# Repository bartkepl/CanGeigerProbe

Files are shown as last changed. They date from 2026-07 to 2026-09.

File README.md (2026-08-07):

# CanGeigerProbe
## Sonda promieniowania G-M z interfejsem CAN

Polowa sonda promieniowania jonizującego z miniaturową lampą Geigera-Müllera, komunikująca się cyfrowo przez **CAN 2.0B**. Zaprojektowana jako element rozproszonego systemu pomiarowego: wąska sonda cylindryczna w obudowie aluminiowej, jedno złącze M12, micropower, odporność EMC klasy przemysłowej.







> **Status:** schemat (6 arkuszy hierarchicznych) i layout PCB zakończone, pliki produkcyjne wygenerowane — przed zamówieniem prototypu. Firmware na etapie szkieletu bring-up.

Inspiracja: sondy Polon-Alfa (DPO-G, ZR-1) — jedna sonda, cyfrowe wyjście do jednostki nadrzędnej, wymienność lamp.

---

## Płytka

Render 3D aktualnego layoutu (KiCad 10, 4 warstwy, 86 × 29.9 mm, wycięcie pod złącze M12 na lewej krawędzi):

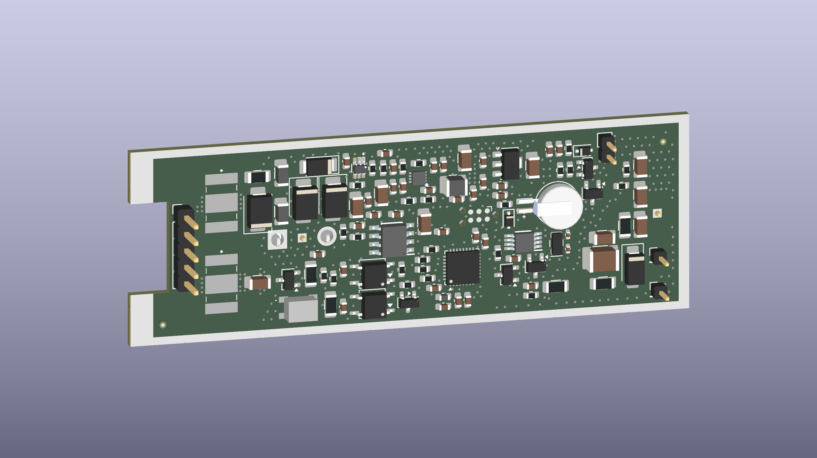
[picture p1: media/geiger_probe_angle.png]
Sonda G-M — widok pod kątem


| Góra (TOP) | Dół (BOTTOM) |
|---|---|
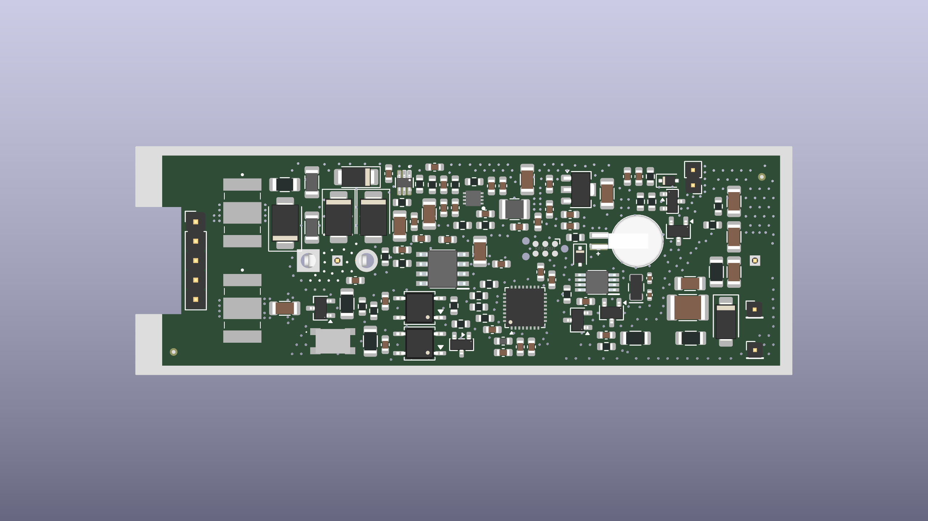
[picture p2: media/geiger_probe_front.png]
TOP
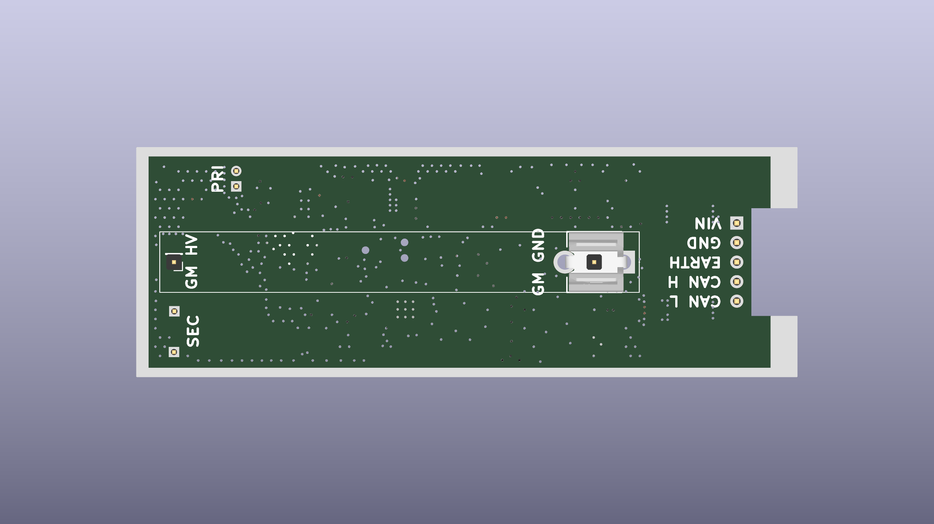
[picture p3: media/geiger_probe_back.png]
BOTTOM
|  |  |

Cała elektronika mieści się na jednej stronie; spód pozostaje niemal pusty — rezerwa na strefę HV (widoczny prostokąt creepage z pinami anody i lampy), pole lutownicze wyprowadzeń transformatora oraz uziemienie obudowy. Transformator flybacka jest **off-board** (skręcona para przewodów 4–6 cm).

---

## Najważniejsze cechy

- **Programowalne HV 350–550 V** — jedna sonda obsługuje wiele typów lamp, setpoint ustawiany przez CAN bez zmian sprzętowych.
- **Micropower** — pobór idle rzędu setek µA dzięki buckowi LT8606 (Iq 2.5 µA), MCU w Stop 2 i podwójnemu wybudzaniu (RTC + aktywność magistrali).
- **Flyback sterowany deterministycznie z MCU** — brak dedykowanego kontrolera PWM; TIM2 generuje burst, ADC mierzy HV, firmware zamyka pętlę bang-bang.
- **CAN 2.0B (29-bit ID)** z wybudzaniem na aktywność magistrali, 125 kbit/s – 1 Mbit/s.
- **Przełączalna terminacja CAN** — split 2×59 Ω + 4.7 nF załączany dwoma PhotoMOS-ami z GPIO (sonda na końcu linii vs. w środku, bez zwór).
- **Pomiar własnego poboru prądu** — INA186 A4 (G=200) + shunt 0.5 Ω, rozdzielczość ~2 µA/count; diagnostyka linii i weryfikacja budżetu mocy.
- **Zegar czasu rzeczywistego z podtrzymaniem** — MCP79410 + ogniwo MS621FE; kwarc 32.768 kHz służy też do kalibracji wewnętrznego MSI w STM32.
- **Wymienność lamp** — rezystor gaszący `R12` na PCB dobierany pod konkretną lampę.
- **Odporność EMC** — kaskadowa ochrona coarse→fine (GDT 3-elektrodowe / TVS / CMC / podwójne ferryty), testy IEC 61000-4-2/-4/-5.
- **Obudowa aluminiowa IP67**, złącze M12 5-pin A-coded (standard CANopen CiA 303-1).

---

## Specyfikacja

| Parametr | Wartość |
|---|---|
| Detektor bazowy | DOI-80 (~400 V) |
| Zakres HV | 350–550 V, programowalny |
| Wielkości mierzone | CPS/CPM, moc dawki, dawka skumulowana, prąd zasilania, alarmy progowe |
| Interfejs | CAN 2.0B (extended ID), 125k / 250k / 500k / 1 Mbit |
| Zasilanie | 7–32 V DC, wspólna masa (bez izolacji galwanicznej) |
| Pobór idle | ~200 µA @ 12 V |
| Pobór aktywny | ~3.7 mA @ 12 V (chwilowo), do ~20 mA przy TX CAN @ 7 V |
| Ochrona EMC | ESD ±8 kV, Burst ±2 kV, Surge ±2 kV |
| Złącze | M12 5-pin A-coded (1=Vin, 2=GND, 3=CAN_H, 4=CAN_L, 5=Earth) |
| PCB | 4 warstwy, 86 × 29.9 mm, grubość 1.59 mm |
| Obudowa | Aluminiowa cylindryczna Ø wewn. 25 mm, IP67 |

---

## Kompatybilne lampy G-M

Zmiana lampy = zmiana programowa HV + dobór rezystora gaszącego `R12`.

| Lampa | HV nom. | R12 (quench) | Uwaga |
|---|---|---|---|
| **DOI-80** | ~400 V | **5.1 MΩ** | domyślna |
| SBM-20 / STS-5 | 400 V | 4.7 MΩ | drop-in z DOI-80 |
| SBM-19 | ~400 V | 5.1 MΩ | |
| J305 / M4011 | ~400 V | 4.7 MΩ | lampy chińskie |
| LND712 | 500 V | 10 MΩ | wymaga wyższego HV |

Rezystor HV w obudowie 1206 (HVC1206) — lutowany wg używanej lampy.

---

## Architektura

```
M12 Vin (7-32V) ─▶ Ochrona (GDT+TVS+ferryt) ─▶ shunt 0.5Ω ─▶ LT8606 buck ─▶ +5V ─┬─▶ ATA6561 (CAN)
                                                    │                              │
                                                 INA186 ─▶ ADC                     ├─▶ MCP1700 LDO ─▶ +3.3V ─▶ STM32L432
                                                                                   │                              │
                                                                                   │                     MCP79410 RTC + BT1
                                                                                   │
                                                                                   └─▶ Flyback (Q1 + T1 P18/11) ─▶ +HV
                                                                                                                    │
   Lampa G-M ◀─ R12 (quench) ◀─ dzielnik HV 1GΩ:1MΩ ◀─────────────────────────────────────────────────────────────┘
        │
        └─▶ dzielnik pojemnościowy ─▶ COMP1 (próg z DAC1) ─▶ LPTIM (zliczanie w Stop 2)
```

Kluczowa cecha: **wspólna masa** (star ground), izolacja zapewniona wyłącznie przez TVS/GDT; `Earth` (obudowa) oddzielona od `GND` sygnałowej i łączona tylko przez Y-cap 1 nF/2 kV. Flyback „śpi" i budzi się kilka razy na sekundę — stąd pobór na poziomie µA.

### Arkusze schematu

| Arkusz | Plik | Zawartość |
|---|---|---|
| root | [geiger_probe.kicad_sch](pcb/geiger_probe.kicad_sch) | połączenia hierarchiczne |
| PWR | [pwr.kicad_sch](pcb/pwr.kicad_sch) | buck LT8606, LDO MCP1700, INA186, dzielnik VIN_SENSE |
| MCU | [mcu.kicad_sch](pcb/mcu.kicad_sch) | STM32L432, RTC MCP79410, kwarc 32k, SWD (Tag-Connect) |
| HV | [hv.kicad_sch](pcb/hv.kicad_sch) | flyback (trafo, Q1, snubber RCD), dzielnik HV, detektor GM + shaper |
| CAN_BUS | [can_bus.kicad_sch](pcb/can_bus.kicad_sch) | ATA6561, terminacja PhotoMOS |
| PROTECTION | [prot.kicad_sch](pcb/prot.kicad_sch) | ochrona Vin i CAN, złącze M12 |

Wyrenderowane PDF-y: [schemat](prod/sch/geiger_probe.pdf) · [PCB](prod/pcb/geiger_probe.pdf) · [interaktywny BOM](prod/ibom/geiger_probe_ibom.html).

---

## Kluczowe komponenty

| Blok | Element | Uwaga |
|---|---|---|
| Buck | LT8606IDC#TRPBF | DFN-8, Iq 2.5 µA (zawsze Burst Mode), Vref FB 0.778 V — jedyny element spoza TME |
| LDO 3.3 V | MCP1700-3302E/MB | SOT-89, Iq 1.6 µA |
| Current sense | INA186A4IDCKR + 0.5 Ω | 40 V CM, G=200, pin EN — pomiar poboru sondy |
| MCU | STM32L432KCU6 | bxCAN, LPTIM, COMP1, TIM2, ADC, DAC1 |
| RTC | MCP79410-I/MS + MS621FE-FL11E | RTC/EEPROM I2C z podtrzymaniem, kwarc 32.768 kHz |
| CAN | ATA6561-GAQW-N | zamiennik TJA1042 dostępny w TME |
| Terminacja CAN | 2× GAQY212GS + 2× 59 Ω + 4.7 nF | split przełączalny, sterowany BSS138 |
| Transformator | własny P18/11-3F3, 17:510 | nawijany ręcznie, off-board |
| Klucz flyback | DMN3404L | 30 V, snubber RCD (BAV21WS) clamp do +5 V |
| Dioda HV | STTH112A | 1200 V |
| Dzielnik HV | 2× HVC1206 500 MΩ | /1001, ochrona ADC diodami BAV199 |
| Ochrona Vin | 3R090-5S (GDT) + SMBJ33CA + PMEG6030EP + 2× SMBJ36A | kaskada coarse→fine, podwójny ferryt BLM31 |
| Ochrona CAN | 3R090-5S + CDSOT23-T24CAN + ACT45B-510 | GDT, dedykowany TVS, CMC |

Pełna lista: [prod/bom/](prod/bom/) (generowana z KiCad, nietrackowana w git). Szacunkowy koszt kompletu: **~160–200 zł**.

---

## Transformator (DIY)

Najbardziej „ręczna" część projektu — rdzeń kubełkowy **P18/11-3F3**, mocowany śrubą **M2 A2 (nierdzewna, niemagnetyczna!)** z podkładkami nylonowymi chroniącymi kruchy ferryt.

- Pierwotne: **17 zw** drut 0.30 mm CuL
- Wtórne: **510 zw** drut 0.10 mm CuL (przekładnia 1:30)
- Szczelina: Kapton 100 µm między połówkami
- Parametry docelowe: Lp ≈ 75 µH, Ls ≈ 67 mH, leakage < 1.5 µH, izolacja P/S > 1 GΩ

Zasilany z **+5 V** (nie z Vin), snubber RCD clamp do +5 V — recykling energii rozproszenia, Vds ~20 V, cichy EMC. Procedura nawijania, obliczenia i testy (hi-pot 1 kV/60 s) — patrz dokumentacja projektowa.

---

## Firmware

Projekt STM32CubeIDE w [firmware/CanGeigerProbe/](firmware/CanGeigerProbe/) — na razie szkielet wygenerowany z CubeMX ([CanGeigerProbe.ioc](firmware/CanGeigerProbe/CanGeigerProbe.ioc)) z inicjalizacją ADC1, CAN1, COMP1, DAC1, I2C1 i TIM2. Logika aplikacji (pętla HV, zliczanie w Stop 2, protokół CAN) do napisania.

---

## Roadmap

- [x] **Faza 1** — projekt: topologia, dobór komponentów, obliczenia, EMC, budżet mocy
- [ ] **Faza 2** — prototyp transformatora (nawinięcie, strojenie, testy)
- [x] **Faza 3** — schemat i layout PCB w KiCad (strefy HV / analog / cyfrowe), pliki produkcyjne wygenerowane
- [ ] **Faza 3b** — zamówienie PCB, montaż sekcyjny, bring-up sprzętowy
- [ ] **Faza 4** — firmware (LPTIM+COMP w Stop 2, pętla HV, bxCAN + wake-up, RTC/kalibracja MSI, current-sense, protokół)
- [ ] **Faza 5** — kalibracja HV per lampa, kalibracja CPS→µSv/h (Cs-137), testy EMC
- [ ] **Faza 6** — mechanika: obudowa Al, montaż M12, testy IP67

---

## Struktura repozytorium

```
.
├── media/          # rendery 3D płytki
├── pcb/            # projekt KiCad 10 (schemat hierarchiczny, PCB, biblioteki lokalne, modele 3D)
├── prod/           # pliki produkcyjne: gerbery (.zip), PDF schematu i PCB, interaktywny BOM
├── sim/            # symulacje LTspice (flyback HV, LT8606)
└── firmware/       # projekt STM32CubeIDE (STM32L432, szkielet bring-up)
```

Pliki produkcyjne generowane są jobsetami KiCad: [gen_prod.kicad_jobset](pcb/gen_prod.kicad_jobset) (PDF + BOM), [gen_gerber.kicad_jobset](pcb/gen_gerber.kicad_jobset) (gerbery + wiertła), [gen_media.kicad_jobset](pcb/gen_media.kicad_jobset) (rendery 3D).

---

## Referencje

- Analog Devices **CN-0536** — Geiger Counter Circuit (odczyt z anody, dzielnik pojemnościowy, komparator)
- STM32L432: RM0394, DS11453; bxCAN: AN2606, AN5028
- LT8606 (Analog Devices), MCP1700 / MCP79410 / ATA6561 (Microchip), INA186 (TI)
- Ferroxcube P18/11, materiał 3F3; EPCOS/TDK B65651/B65652
- IEC 61000-4-2/-4/-5; EN 61326-1; EN 61000-6-2
- CAN 2.0B: ISO 11898-1/-2; CANopen CiA 301, CiA 303-1; M12: IEC 61076-2-101
- Polski podręcznik metrologii promieniowania — układy pracy liczników DOI/BOI/GOI

---

## Licencja

MIT

---

> ⚠️ **Uwaga bezpieczeństwa:** urządzenie generuje napięcie ~350–550 V. Zachowaj ostrożność przy uruchamianiu i pomiarach obwodów HV.

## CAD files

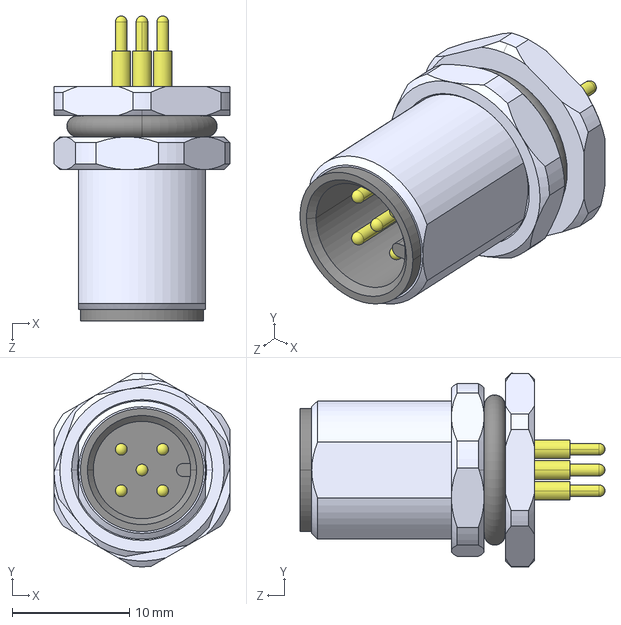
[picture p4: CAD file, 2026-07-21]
pcb/lib_local/CDM1209-05A-MP-F12-67.step
15.0 x 16.5 x 26.0 mm
CDM1209 HOUSING
PINS_MALE_REAR_5P

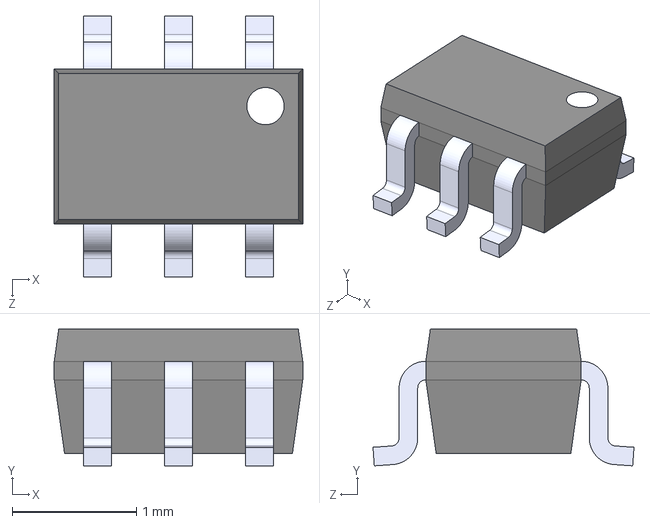
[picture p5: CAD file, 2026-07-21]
pcb/lib_local/INA186A4IDCKR.step
2.00 x 1.10 x 2.10 mm

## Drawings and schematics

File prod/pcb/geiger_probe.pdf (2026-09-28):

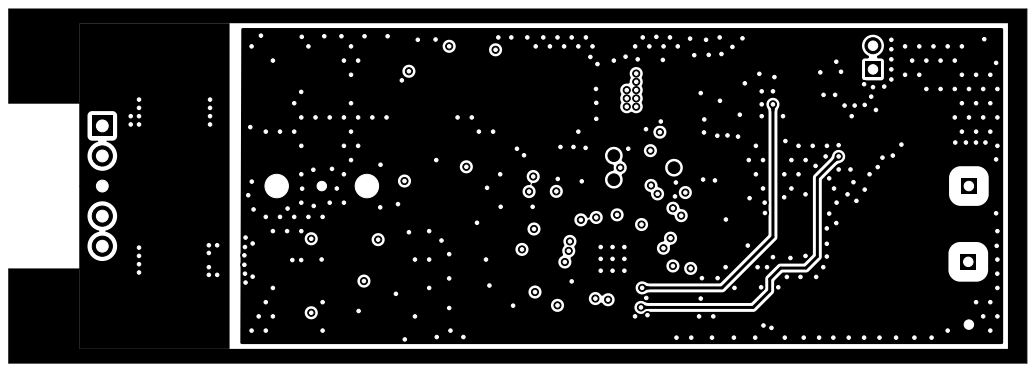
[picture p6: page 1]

Size: A4 | Rev:
KiCad E.D.A. 10.0.4 | Id: 1/6

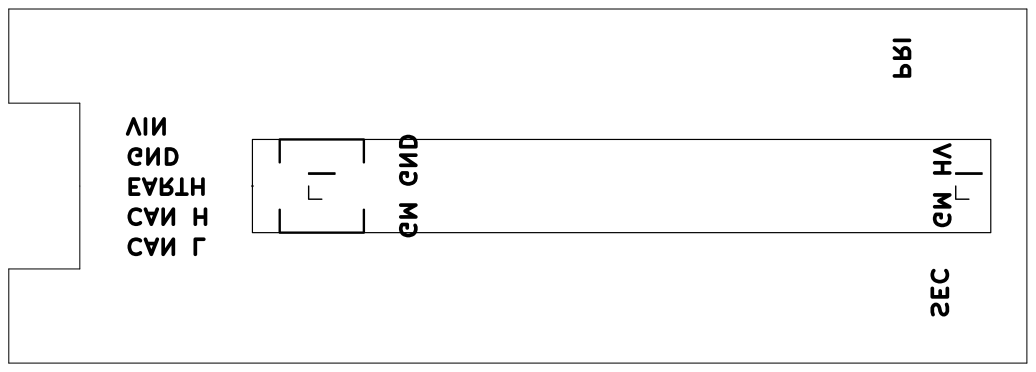
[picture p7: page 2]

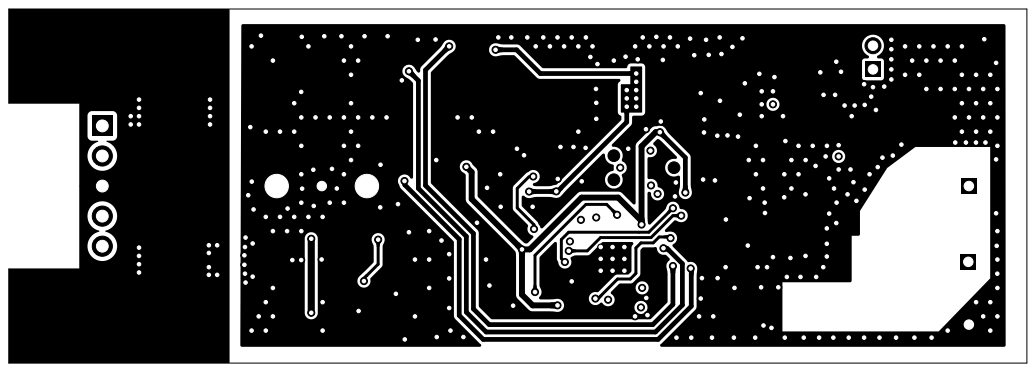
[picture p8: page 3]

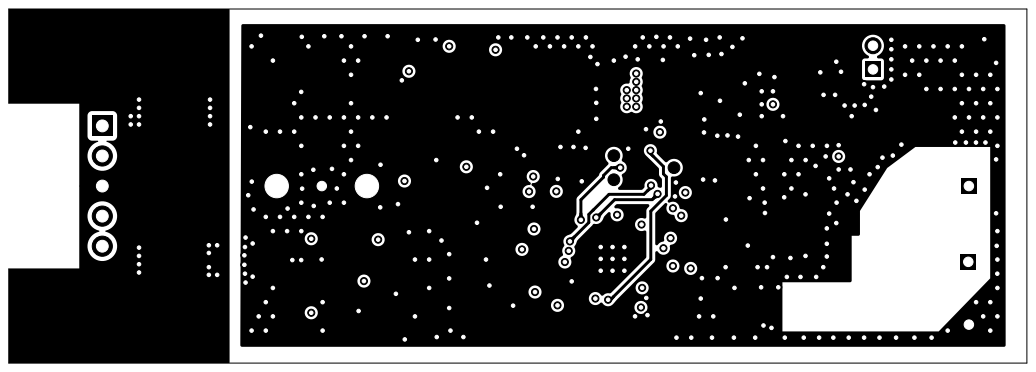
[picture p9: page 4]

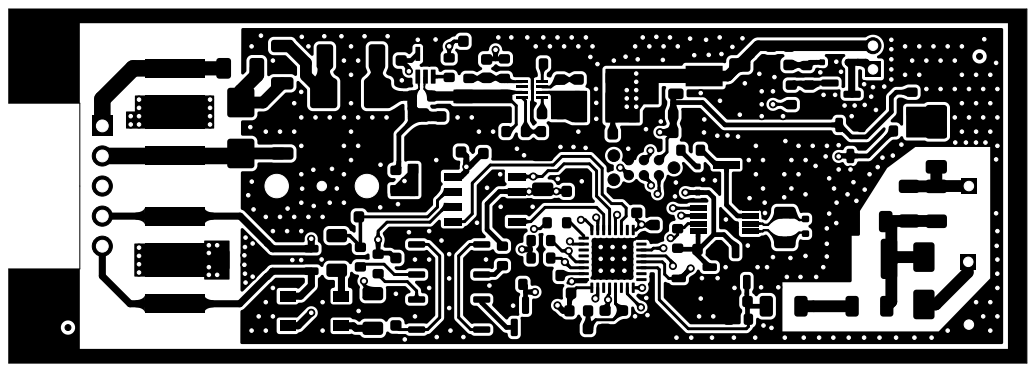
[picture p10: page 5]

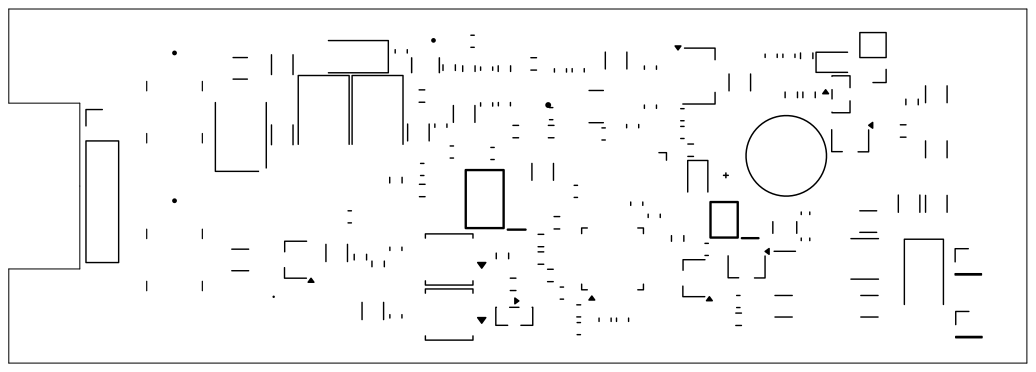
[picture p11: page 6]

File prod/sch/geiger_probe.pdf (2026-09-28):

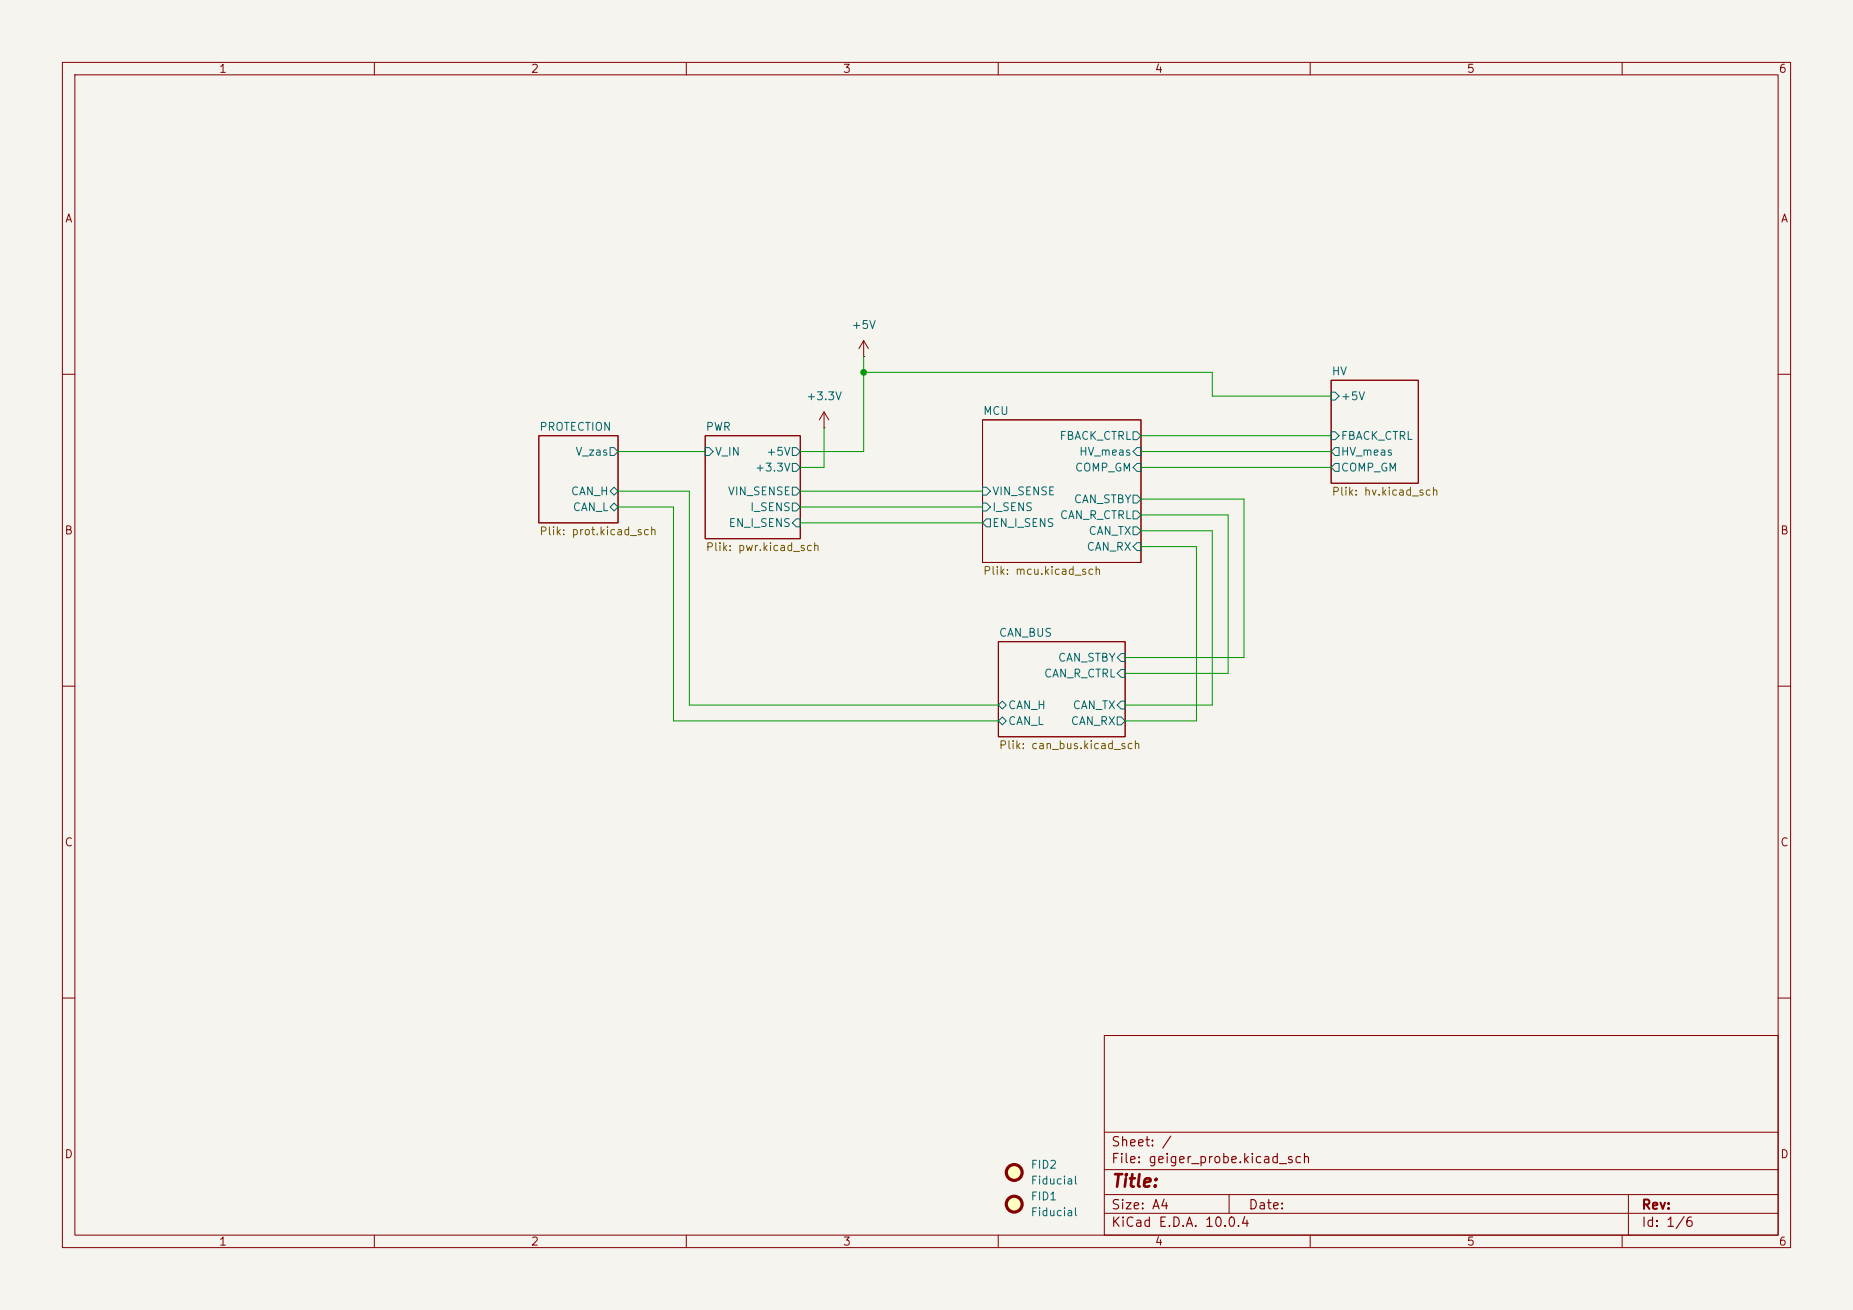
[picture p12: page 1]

Size: A4 | Rev:
KiCad E.D.A. 10.0.4 | Id: 1/6

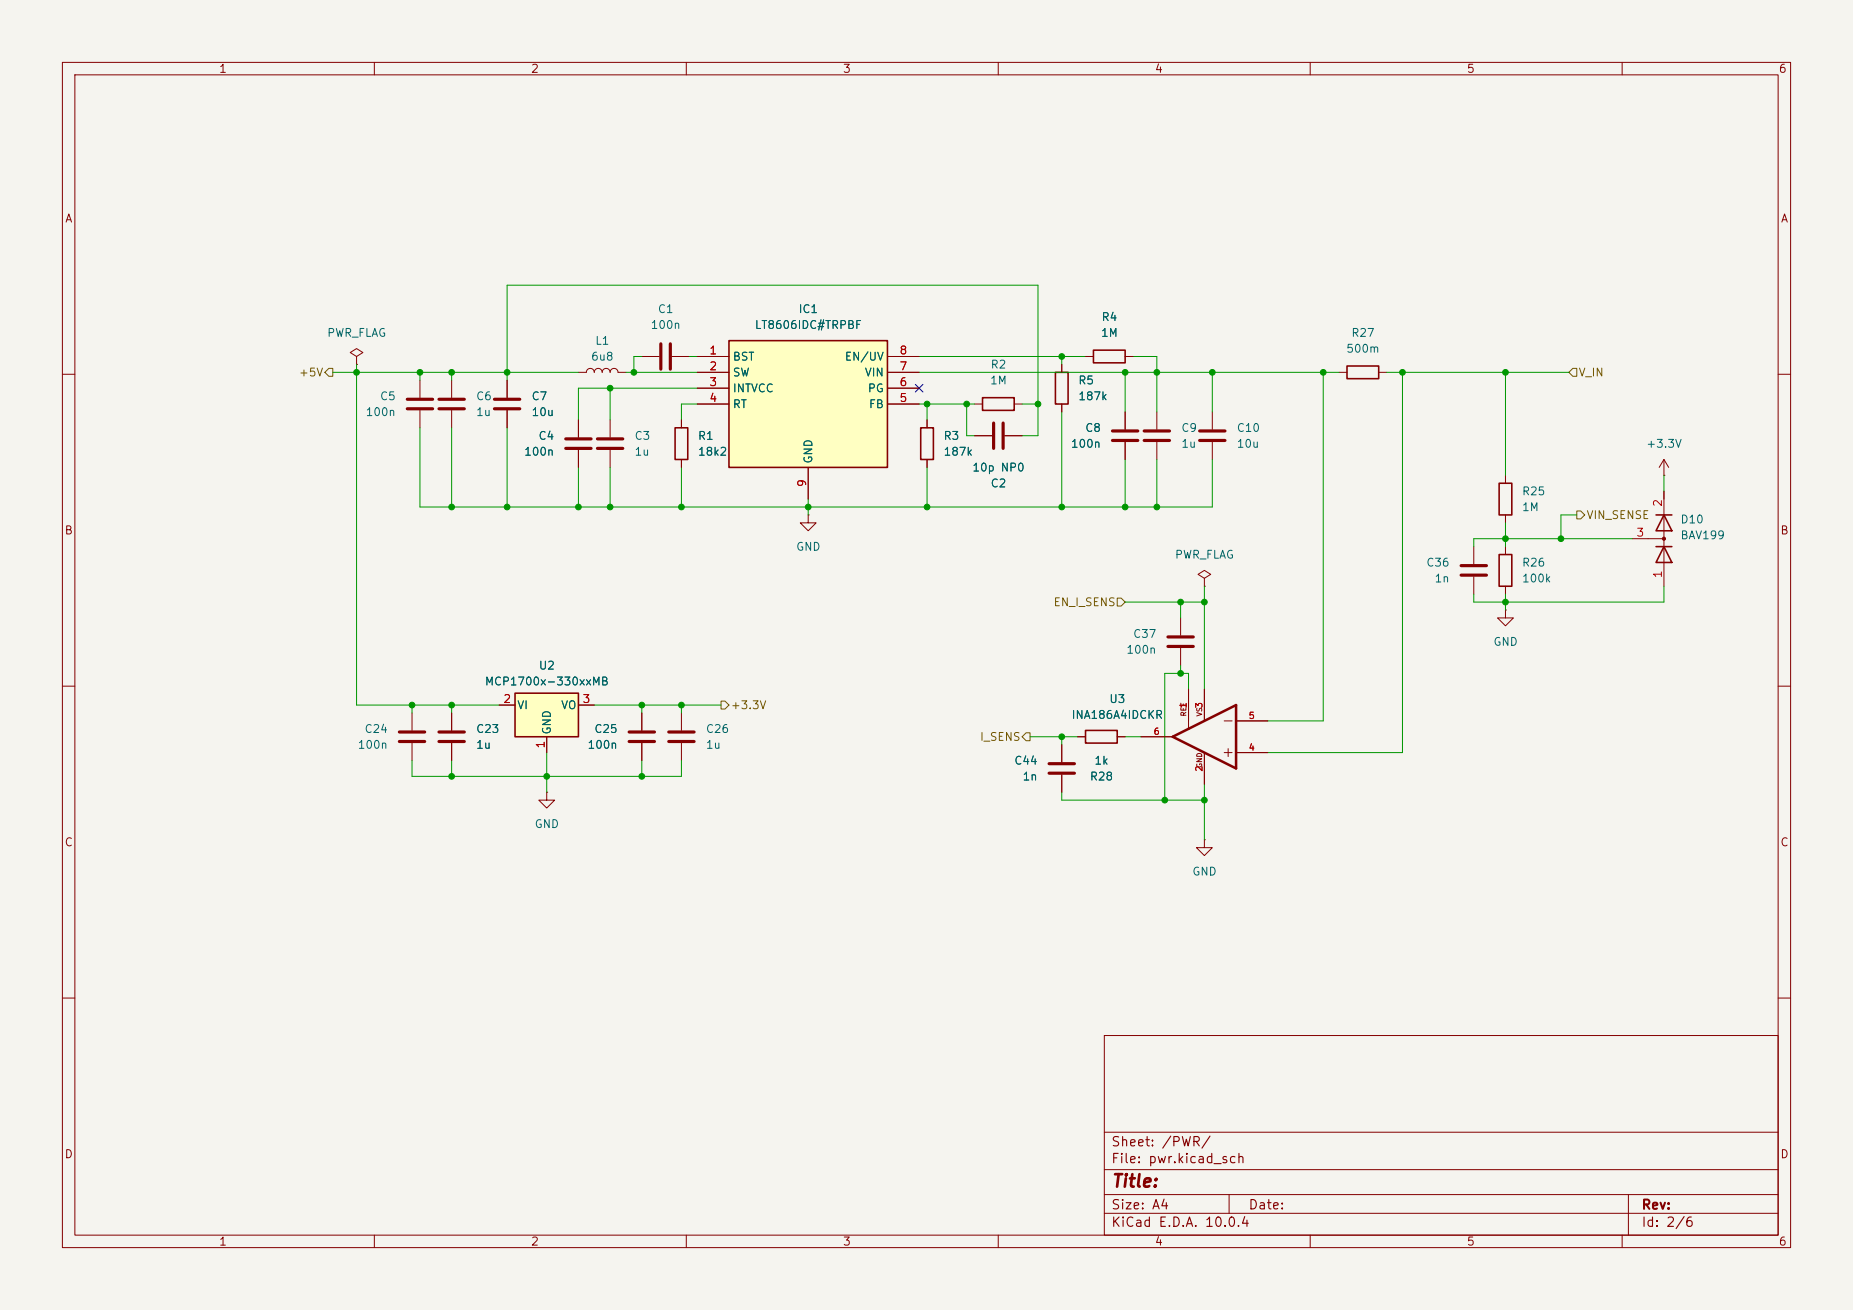
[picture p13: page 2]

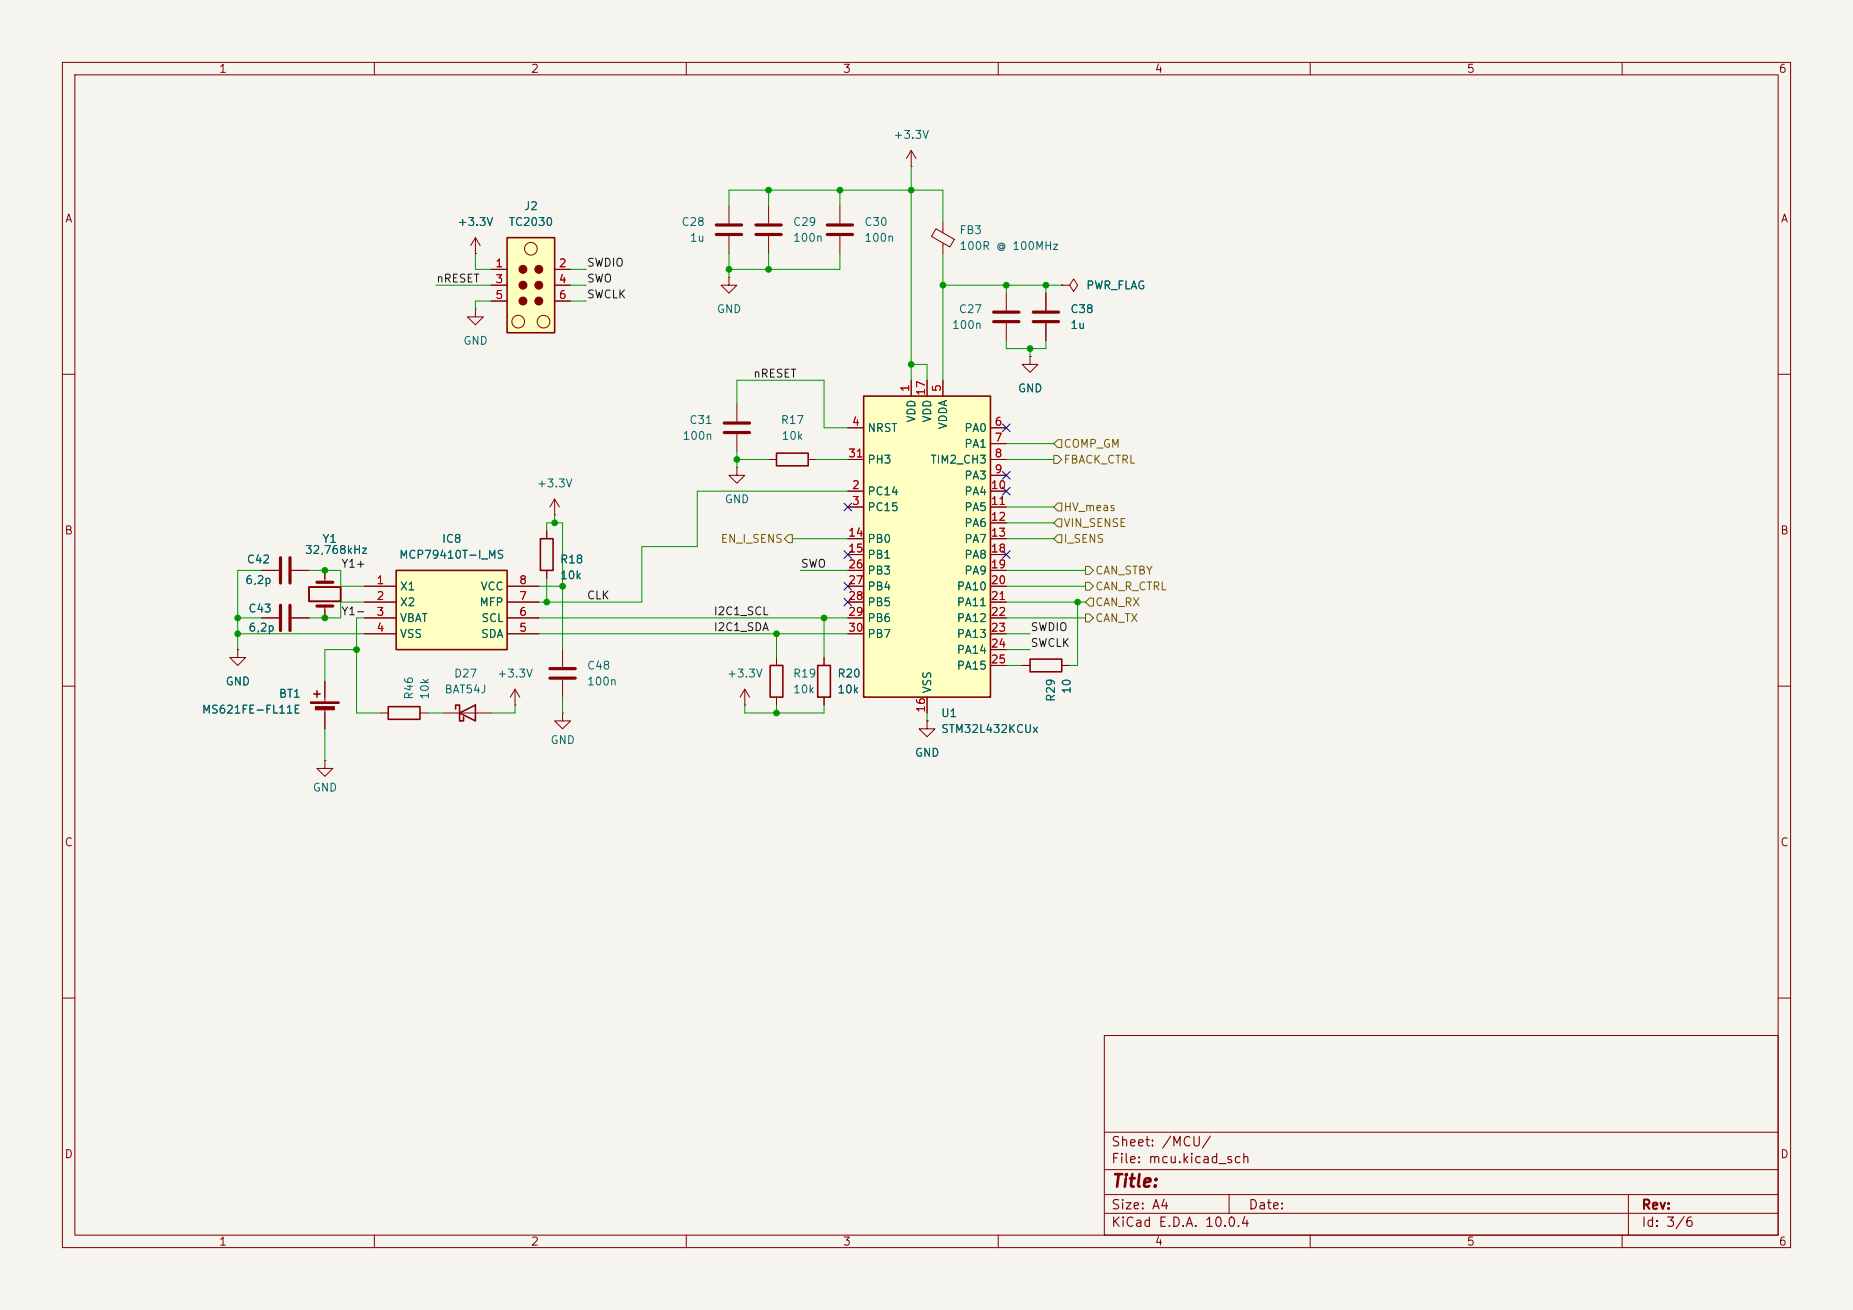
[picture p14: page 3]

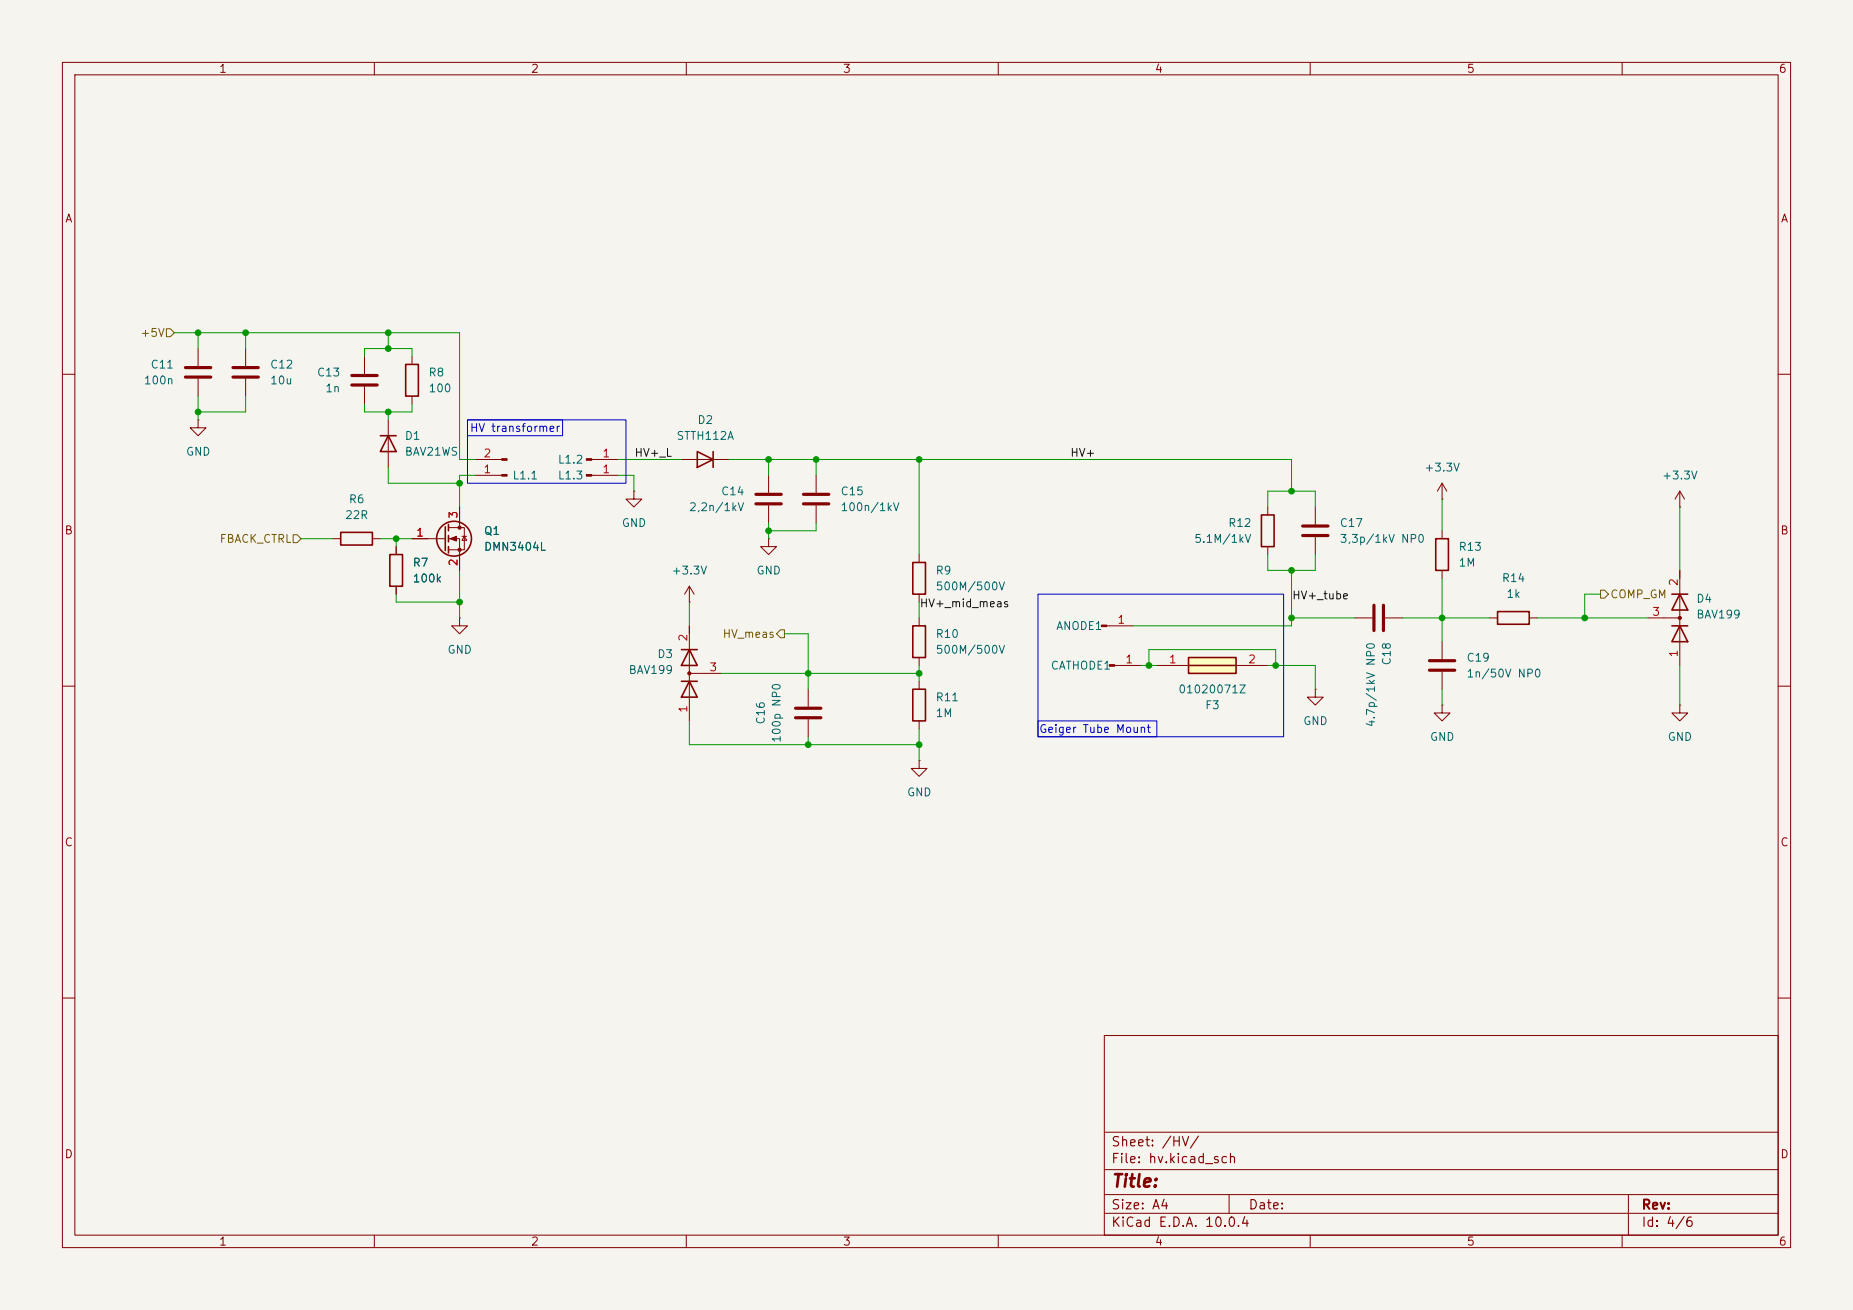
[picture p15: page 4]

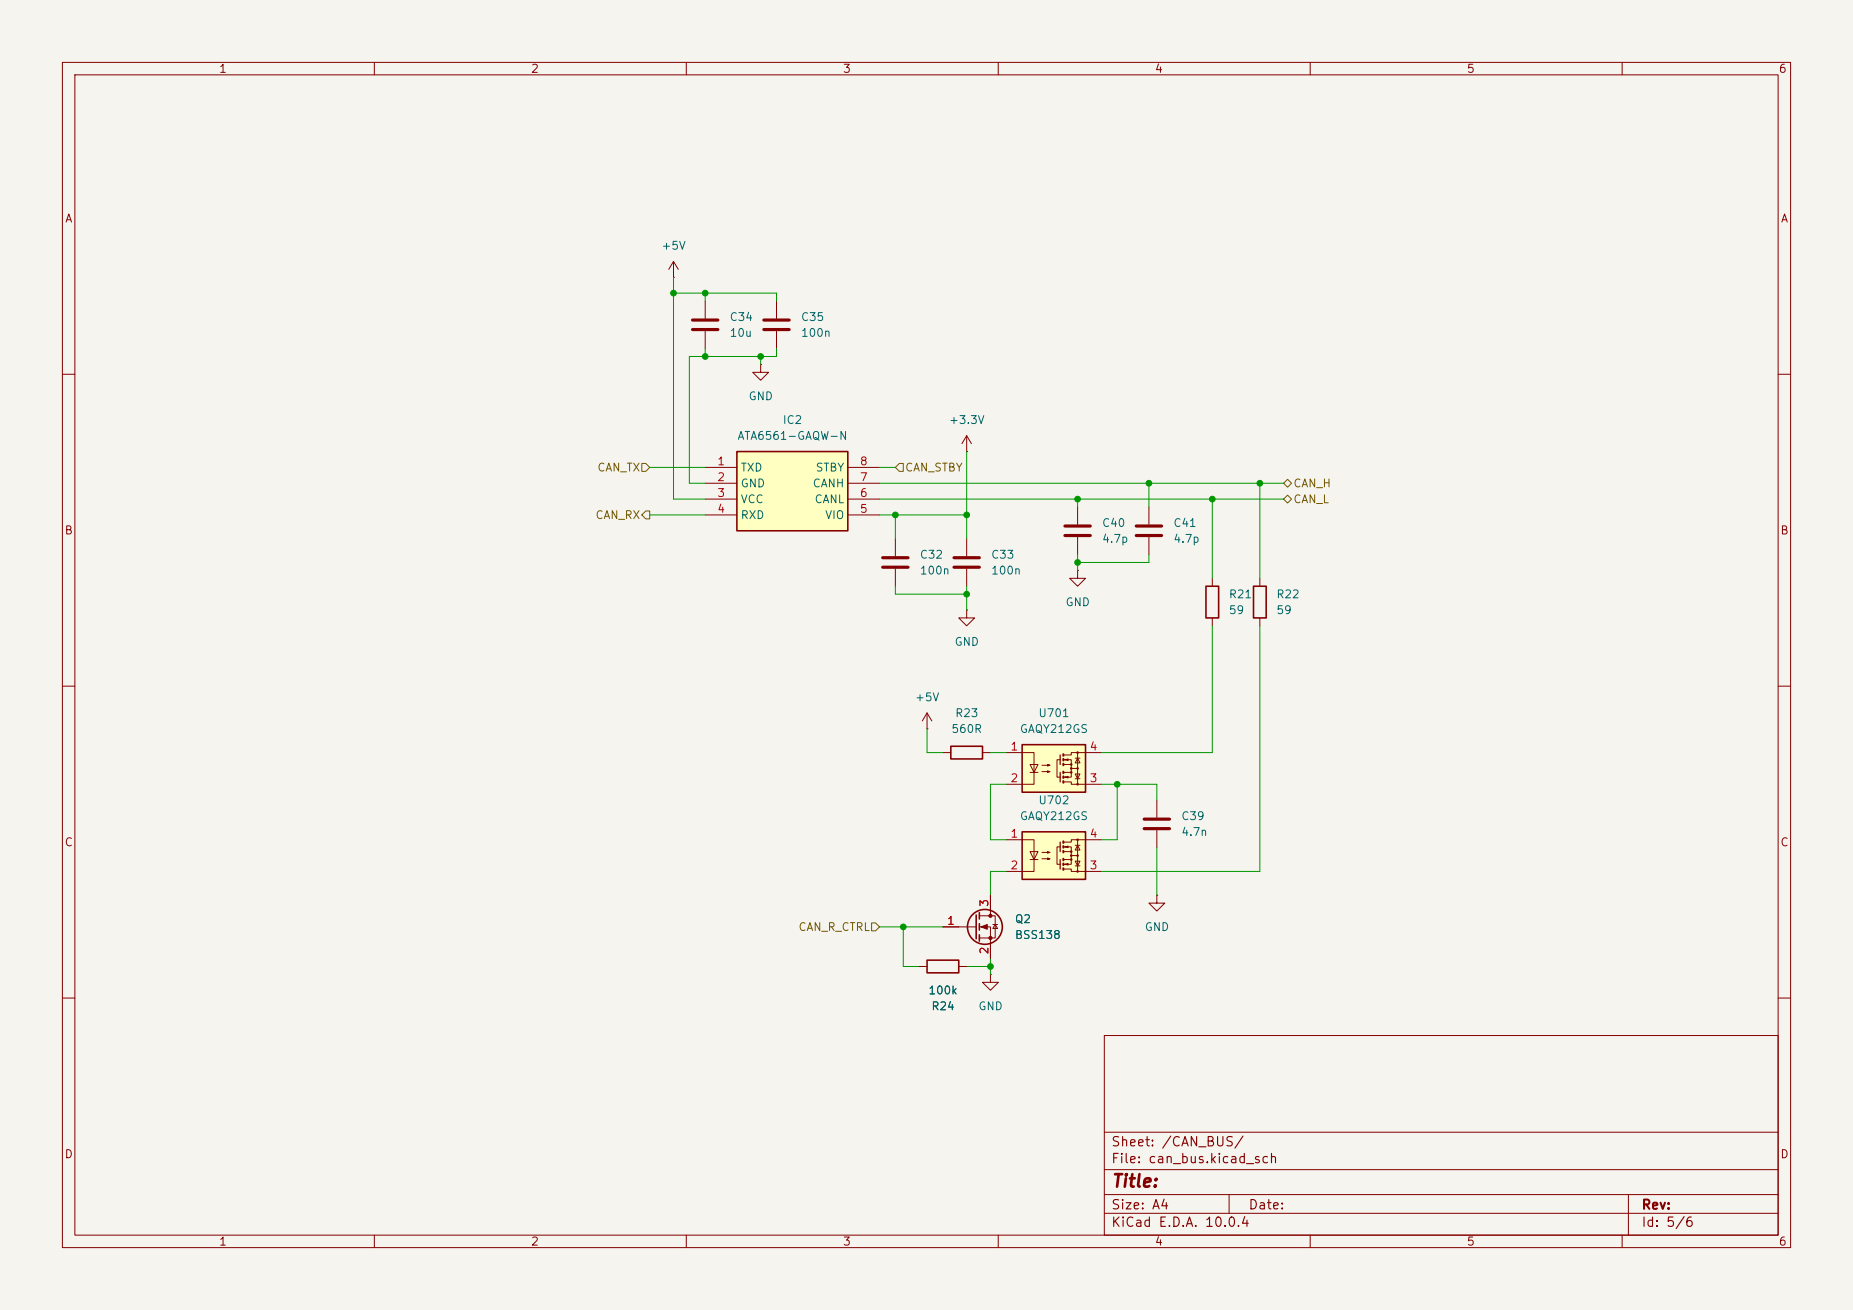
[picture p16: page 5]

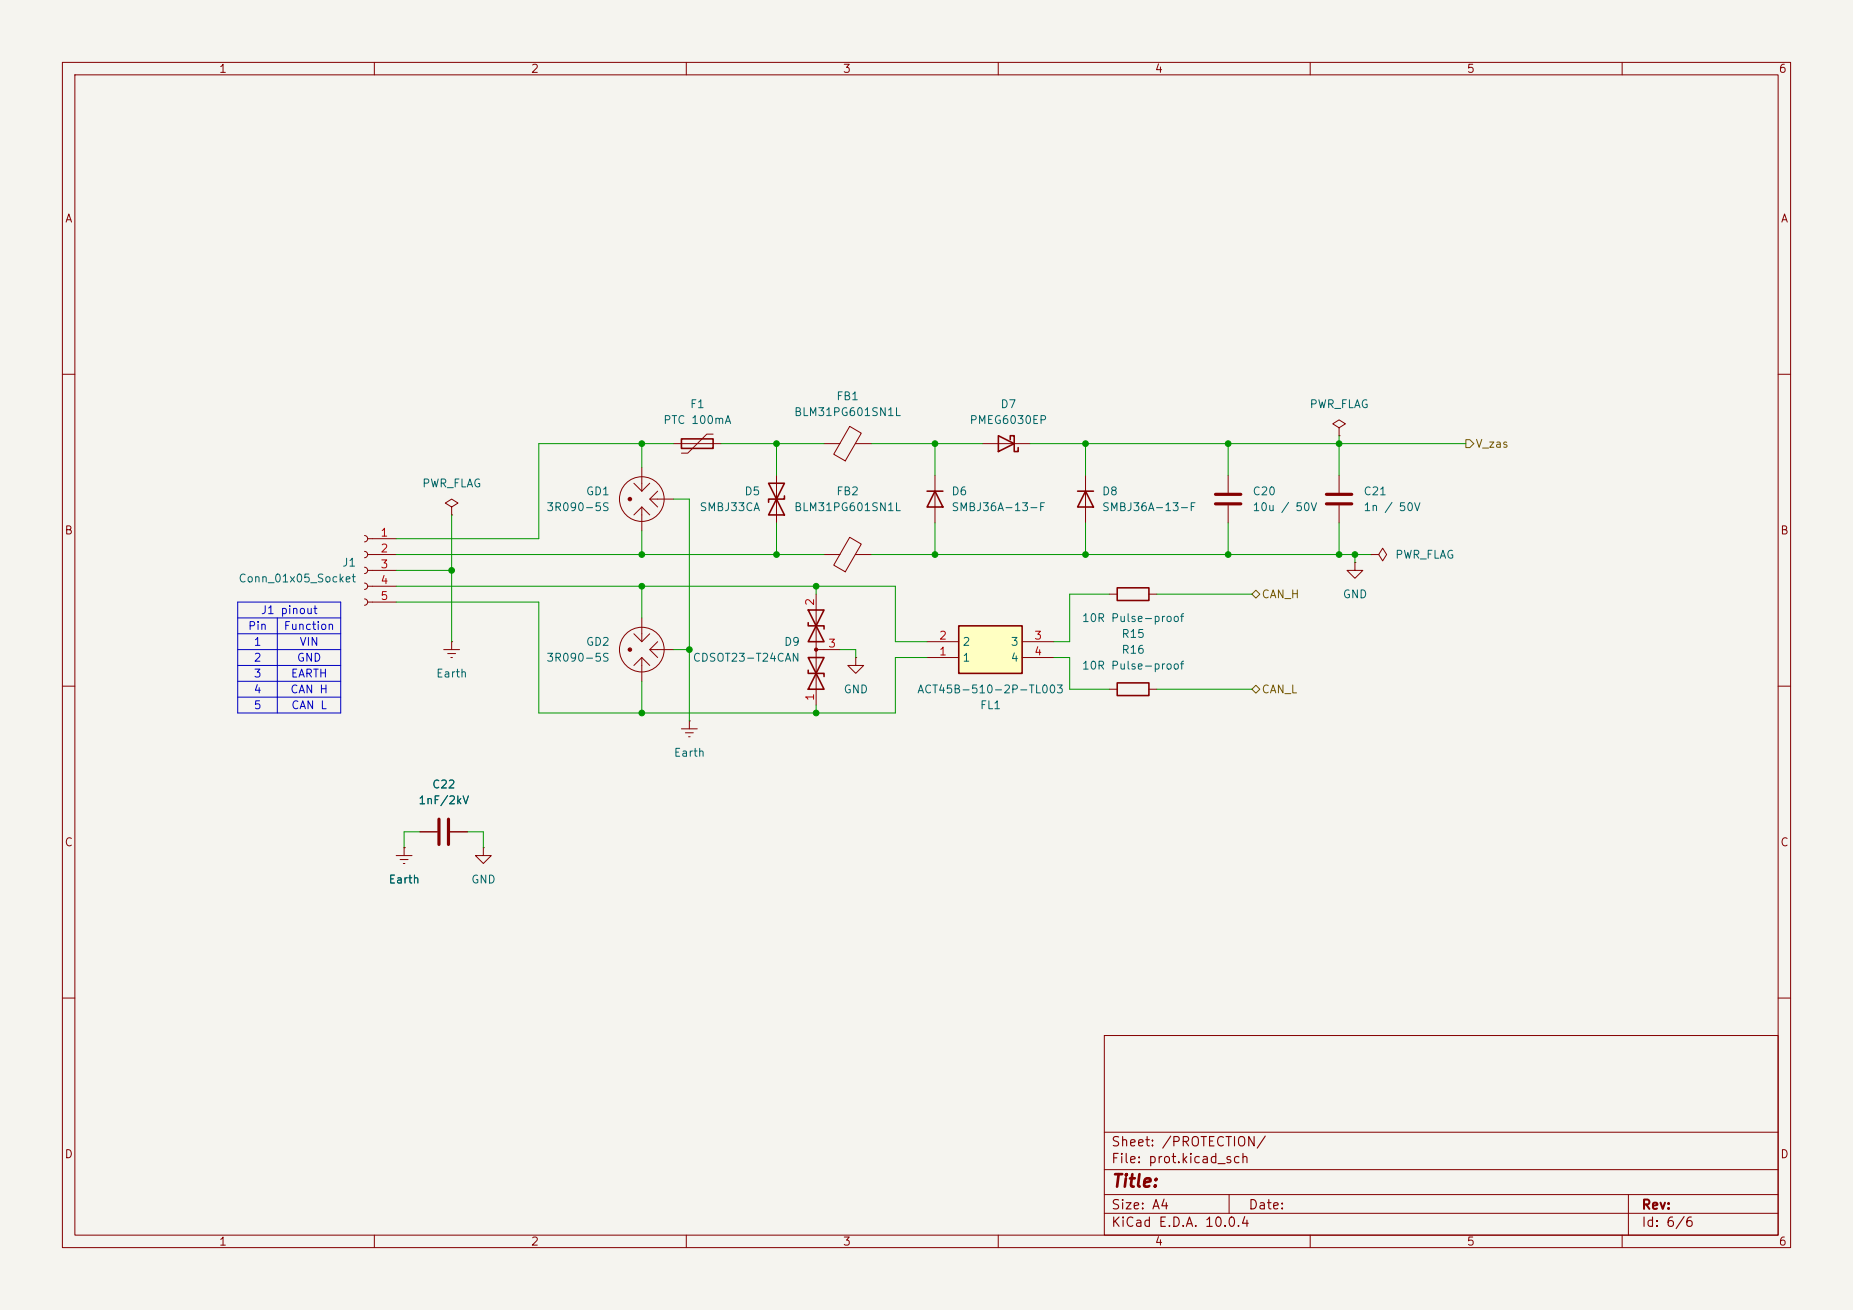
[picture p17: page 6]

J1 pinout Pin | Function 1 VIN

2 | GND
3 | EARTH
4 | CAN H

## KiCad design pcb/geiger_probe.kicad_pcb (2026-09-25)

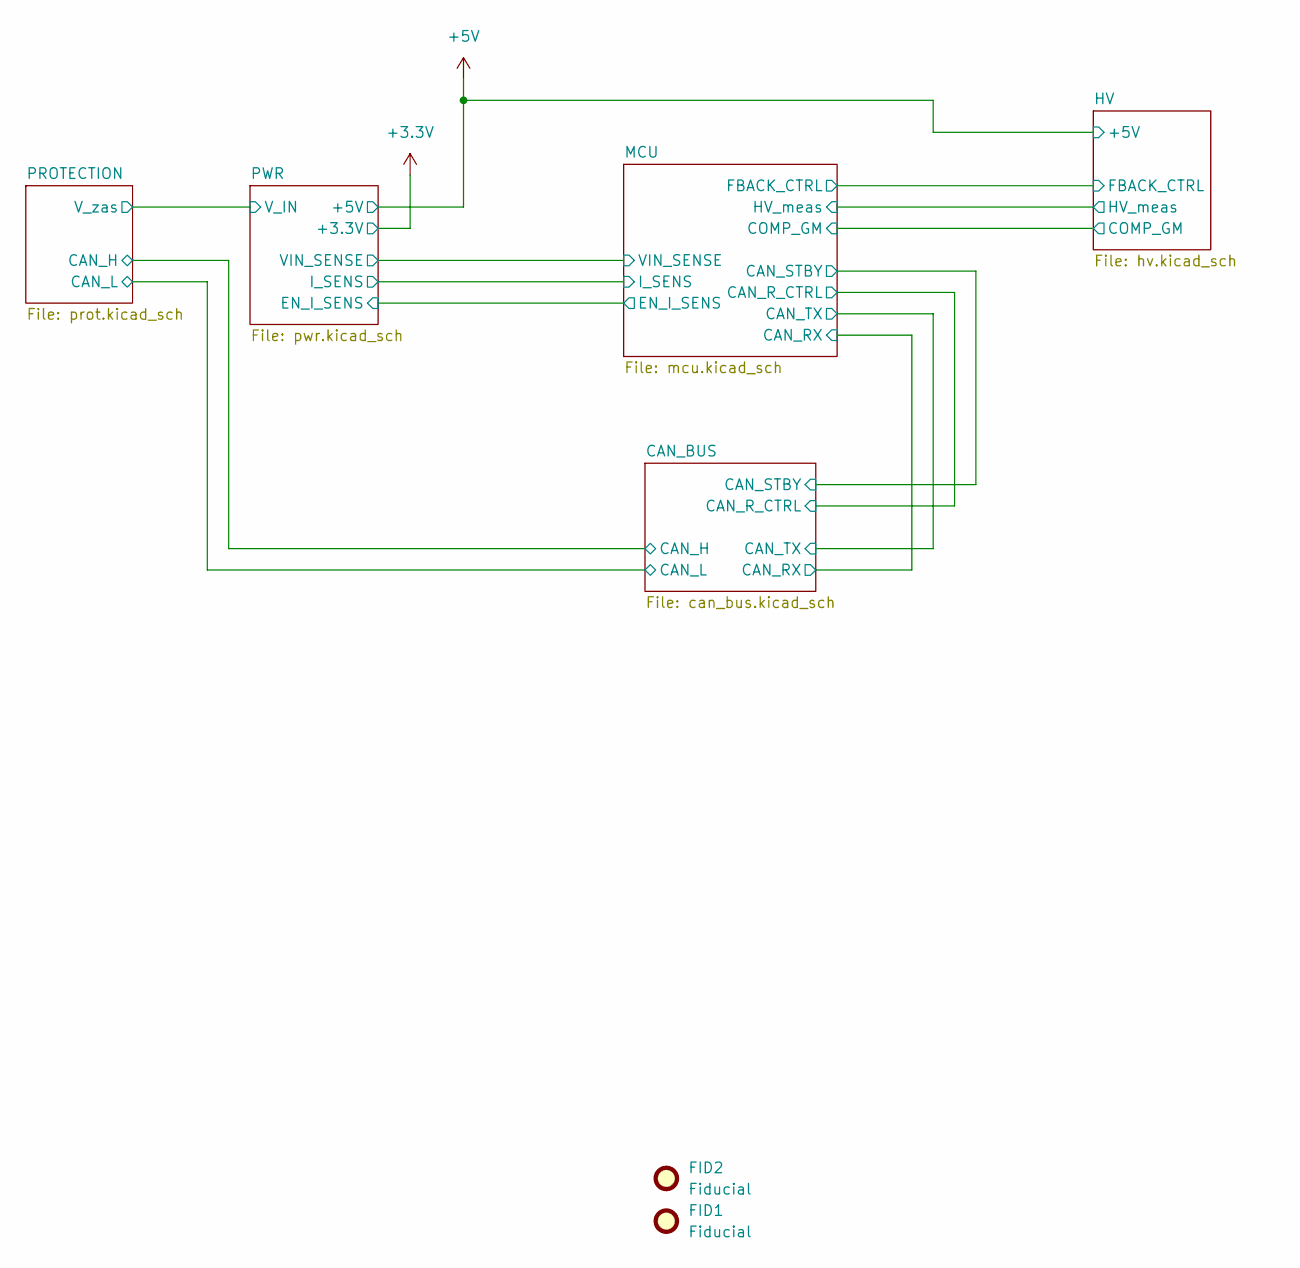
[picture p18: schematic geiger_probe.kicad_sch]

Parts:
FID1, FID2: Fiducial; Fiducial_0.5mm_Mask1mm

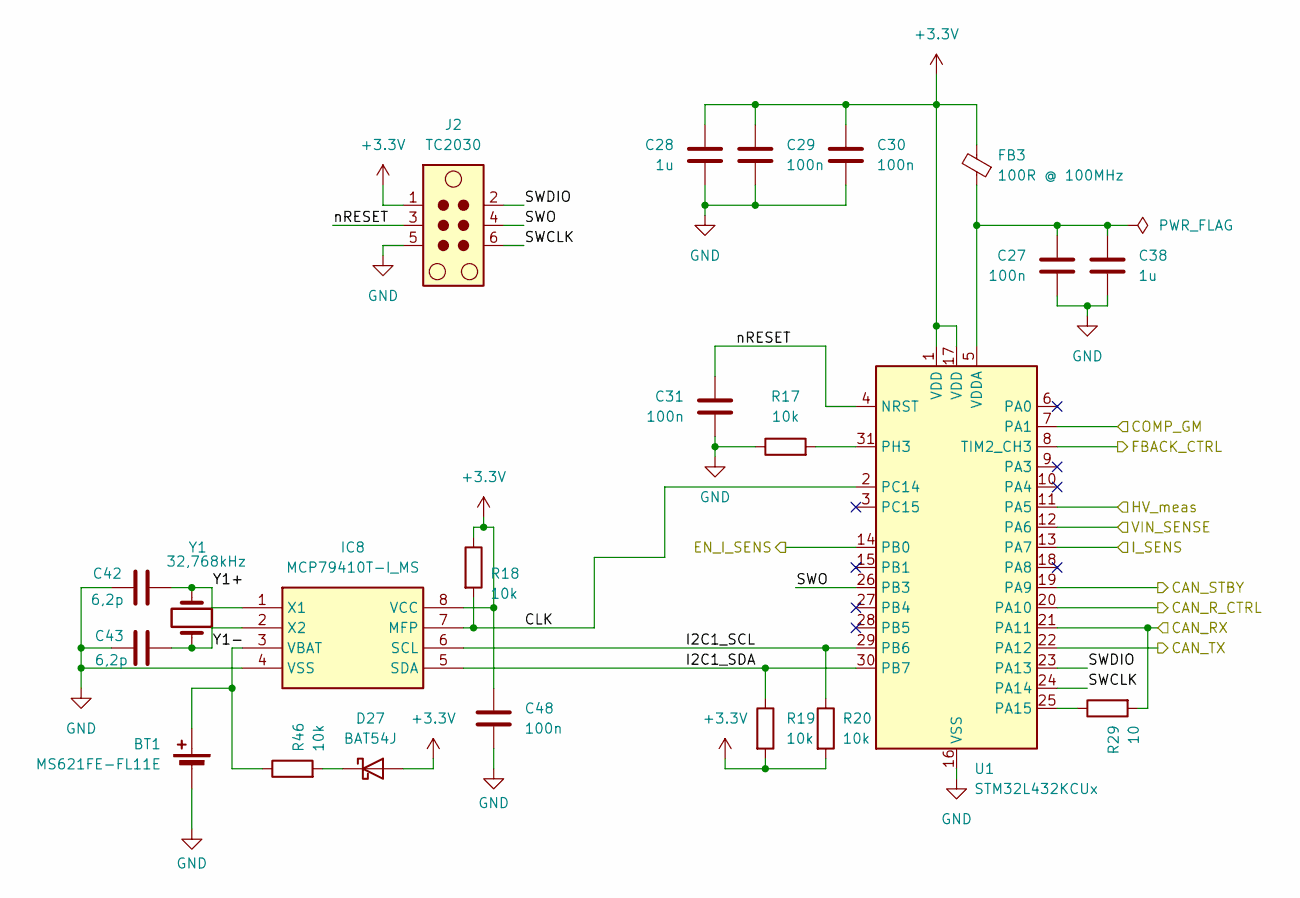
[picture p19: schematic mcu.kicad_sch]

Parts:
BT1: MS621FE-FL11E; BAT_MS621FE-FL11E; Manufacturer_Part_Number MS621FE-FL11E
C27, C29, C30, C31, C48: 100n; C_0603_1608Metric
C28, C38: 1u; C_0603_1608Metric
C42, C43: 6,2p; C_0402_1005Metric
D27: BAT54J; D_SOD-323F; Manufacturer_Part_Number BAT54J
FB3: 100R @ 100MHz; L_0603_1608Metric; Manufacturer_Part_Number WLBD1608HCU101TL
IC8: MCP79410T-I_MS; SOP65P490X110-8N; Mouser Part Number 579-MCP79410T-I/MS
J2: TC2030; Tag-Connect_TC2030-IDC-NL_2x03_P1.27mm_Vertical
R17, R18, R19, R20, R46: 10k; R_0603_1608Metric
R29: 10; R_0603_1608Metric
U1: STM32L432KCUx; QFN-32-1EP_5x5mm_P0.5mm_EP3.1x3.1mm_ThermalVias; Manufacturer_Part_Number STM32L432KCU6
Y1: 32,768kHz; Crystal_SMD_MicroCrystal_CC7V-T1A-2Pin_3.2x1.5mm; Manufacturer_Part_Number WTL1X80739BEL

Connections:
+3.3V: C28.1, C29.2, C30.2, C48.1, D27.2 (A), FB3.2, IC8.8 (VCC), J2.1, R18.1, R19.2, R20.2, U1.1 (VDD), U1.17 (VDD); also elsewhere on the board
/CAN_BUS/CAN_RX: R29.2, U1.21 (PA11); also elsewhere on the board
/CAN_BUS/CAN_R_CTRL: U1.20 (PA10); also elsewhere on the board
/CAN_BUS/CAN_STBY: U1.19 (PA9); also elsewhere on the board
/CAN_BUS/CAN_TX: U1.22 (PA12); also elsewhere on the board
/HV/COMP_GM: U1.7 (PA1); also elsewhere on the board
/HV/FBACK_CTRL: U1.8 (TIM2_CH3); also elsewhere on the board
/HV/HV_meas: U1.11 (PA5); also elsewhere on the board
/MCU/CLK: IC8.7 (MFP), R18.2, U1.2 (PC14)
/MCU/EN_I_SENS: U1.14 (PB0); also elsewhere on the board
/MCU/I2C1_SCL: IC8.6 (SCL), R20.1, U1.29 (PB6)
/MCU/I2C1_SDA: IC8.5 (SDA), R19.1, U1.30 (PB7)
/MCU/I_SENS: U1.13 (PA7); also elsewhere on the board
/MCU/SWCLK: J2.6, U1.24 (PA14)
/MCU/SWDIO: J2.2, U1.23 (PA13)
/MCU/SWO: J2.4, U1.26 (PB3)
/MCU/VIN_SENSE: U1.12 (PA6); also elsewhere on the board
/MCU/Y1+: C42.2, IC8.1 (X1), Y1.1
/MCU/Y1-: C43.2, IC8.2 (X2), Y1.2
/MCU/nRESET: C31.2, J2.3, U1.4 (NRST)
GND: BT1.2 (-), C27.1, C28.2, C29.1, C30.1, C31.1, C38.2, C42.1, C43.1, C48.2, IC8.4 (VSS), J2.5, R17.1, U1.16 (VSS), U1.32 (VSS), U1.33 (VSS); also elsewhere on the board
unnamed: BT1.1 (+), IC8.3 (VBAT), R46.1
unnamed: D27.1 (K), R46.2
unnamed: R29.1, U1.25 (PA15)
unnamed: R17.2, U1.31 (PH3)
unnamed: C27.2, C38.1, FB3.1, U1.5 (VDDA)

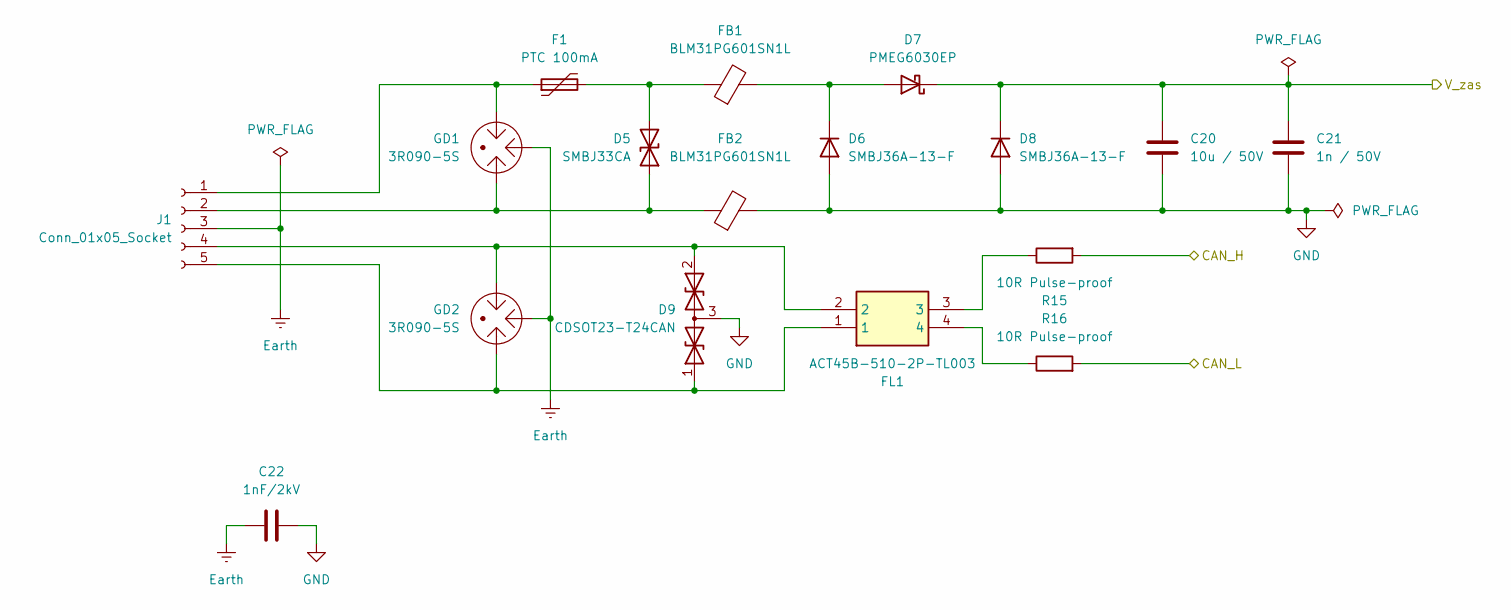
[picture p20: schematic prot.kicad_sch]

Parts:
C20: 10u / 50V; C_1206_3216Metric
C21: 1n / 50V; C_0603_1608Metric
C22: 1nF/2kV; C_1206_3216Metric; Manufacturer_Part_Number 1206B102K202
D5: SMBJ33CA; D_SMB; Manufacturer_Part_Number SMBJ33CA
D6, D8: SMBJ36A-13-F; D_SMB; Manufacturer_Part_Number SMBJ36A-13-F
D7: PMEG6030EP; D_SOD-128; Manufacturer_Part_Number PMEG6030EP
D9: CDSOT23-T24CAN; TSOT-23; Manufacturer_Part_Number CDSOT23-T24CAN
F1: PTC 100mA; Fuse_1206_3216Metric; Manufacturer_Part_Number SN010-60
FB1, FB2: BLM31PG601SN1L; L_1206_3216Metric; Manufacturer_Part_Number BLM31PG601SN1L
FL1: ACT45B-510-2P-TL003; ACT45B1012PTL003; Manufacturer_Part_Number ACT45B-510-2P-TL003; Mouser Part Number 810-ACT45B5102PTL003
GD1, GD2: 3R090-5S; 3R090A5S; Manufacturer_Part_Number Leiditech 3R090-5S
J1: Conn_01x05_Socket; PinHeader_1x05_P2.54mm_Vertical
R15, R16: 10R Pulse-proof; R_1206_3216Metric

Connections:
/CAN_BUS/CAN_H: R15.2; also elsewhere on the board
/CAN_BUS/CAN_L: R16.2; also elsewhere on the board
/PROTECTION/V_zas: C20.1, C21.2, D7.1 (K), D8.1 (K); also elsewhere on the board
Earth: C22.2, GD1.2, GD2.2, J1.3
GND: C20.2, C21.1, C22.1, D6.2 (A), D8.2 (A), D9.3 (common), FB2.2; also elsewhere on the board
unnamed: D5.1 (A1), FB2.1, GD1.3, J1.2
unnamed: D5.2 (A2), F1.2, FB1.1
unnamed: D6.1 (K), D7.2 (A), FB1.2
unnamed: D9.1 (A1), FL1.1, GD2.3, J1.5
unnamed: D9.2 (A2), FL1.2, GD2.1, J1.4
unnamed: FL1.3, R15.1
unnamed: FL1.4, R16.1
unnamed: F1.1, GD1.1, J1.1

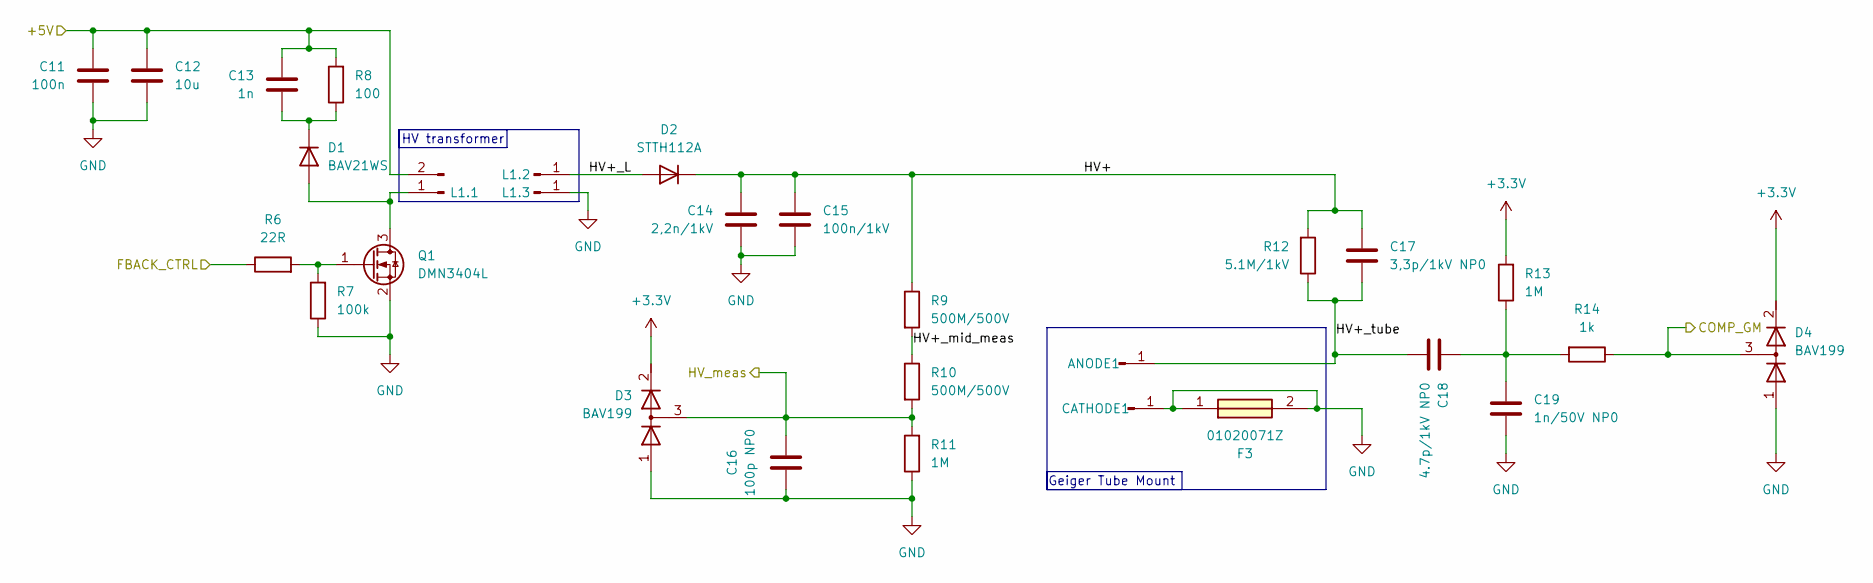
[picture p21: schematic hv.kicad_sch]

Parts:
ANODE1: Conn_01x01_Pin; PinHeader_1x01_P2.00mm_Vertical
C11: 100n; C_0603_1608Metric
C12: 10u; C_1206_3216Metric
C13: 1n; C_0603_1608Metric
C14: 2,2n/1kV; C_1206_3216Metric; Manufacturer_Part_Number CC1206KKX7RC222
C15: 100n/1kV; C_1812_4532Metric; Manufacturer_Part_Number GRM43DR7LW104KW01L
C16: 100p NP0; C_0603_1608Metric; Manufacturer_Part_Number 0603N100J500CT
C17: 3,3p/1kV NP0; C_1206_3216Metric
C18: 4.7p/1kV NP0; C_1206_3216Metric
C19: 1n/50V NP0; C_1206_3216Metric; Manufacturer_Part_Number CC1206KKX7RC222
CATHODE1: Conn_01x01_Pin; PinHeader_1x01_P2.00mm_Vertical
D1: BAV21WS; D_SOD-323F; Manufacturer_Part_Number BAV21WS
D2: STTH112A; D_SMA; Manufacturer_Part_Number STTH112A
D3, D4: BAV199; TSOT-23; Manufacturer_Part_Number BAV199
F3: 01020071Z; Manufacturer_Part_Number 01020071Z; Mouser Part Number 576-01020071Z
L1.1: Conn_01x02_Pin; PinHeader_1x02_P2.00mm_Vertical
L1.2, L1.3: Conn_01x01_Pin; PinHeader_1x01_P2.00mm_Vertical
Q1: DMN3404L; SOT-23; Manufacturer_Part_Number DMN3404L
R6: 22R; R_0603_1608Metric
R7: 100k; R_0603_1608Metric
R8: 100; R_0603_1608Metric
R9, R10: 500M/500V; R_1206_3216Metric; Manufacturer_Part_Number HVC1206T5005JET
R11, R13: 1M; R_0603_1608Metric
R12: 5.1M/1kV; R_1206_3216Metric; Manufacturer_Part_Number HVC1206T5005JET
R14: 1k; R_0603_1608Metric

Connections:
+3.3V: D3.2 (K), D4.2 (K), R13.2; also elsewhere on the board
+5V: C11.2, C12.1, C13.2, L1.1.2, R8.2; also elsewhere on the board
/HV/COMP_GM: D4.3 (common), R14.1; also elsewhere on the board
/HV/FBACK_CTRL: R6.1; also elsewhere on the board
/HV/HV+: C14.1, C15.1, C17.1, D2.1 (K), R9.1, R12.2
/HV/HV+_L: D2.2 (A), L1.2.1 (Pin_1_1)
/HV/HV+_mid_meas: R9.2, R10.1
/HV/HV+_tube: ANODE1.1 (Pin_1_1), C17.2, C18.2, R12.1
/HV/HV_meas: C16.1, D3.3 (common), R10.2, R11.2; also elsewhere on the board
GND: C11.1, C12.2, C14.2, C15.2, C16.2, C19.2, CATHODE1.1 (Pin_1_1), D3.1 (A), D4.1 (A), F3.1, F3.2, L1.3.1 (Pin_1_1), Q1.2 (S), R7.1, R11.1; also elsewhere on the board
unnamed: C18.1, C19.1, R13.1, R14.2
unnamed: D1.2 (A), L1.1.1, Q1.3 (D)
unnamed: C13.1, D1.1 (K), R8.1
unnamed: Q1.1 (G), R6.2, R7.2

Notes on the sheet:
Geiger Tube Mount
HV transformer

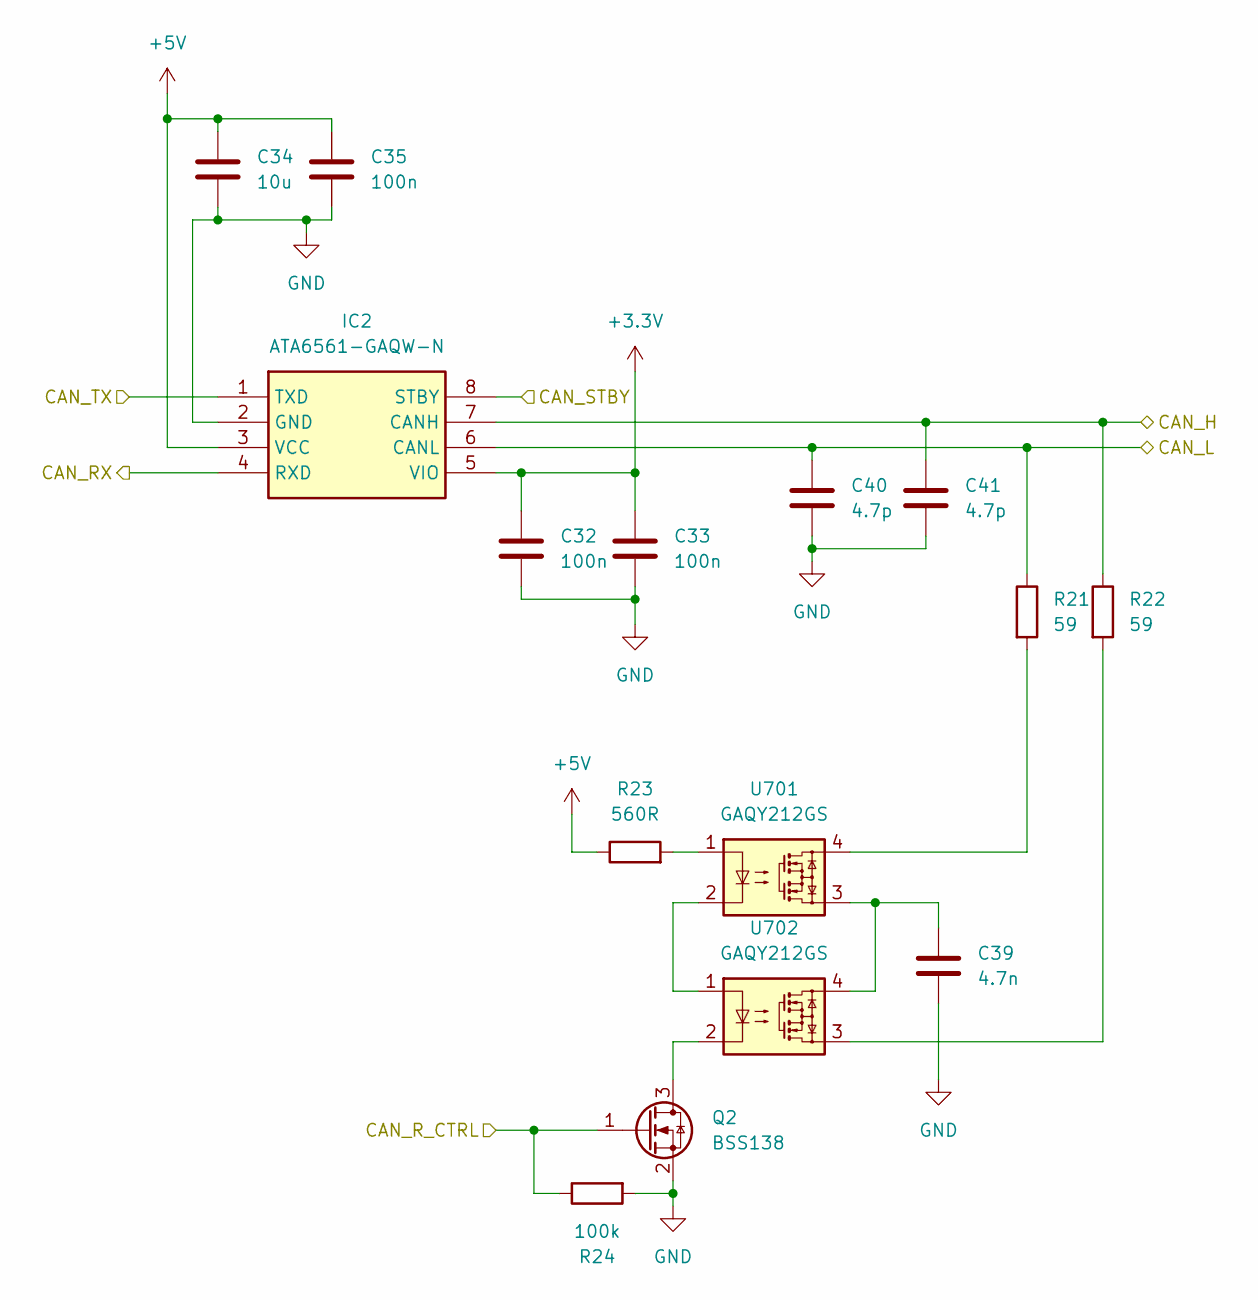
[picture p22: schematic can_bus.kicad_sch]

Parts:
C32, C33, C35: 100n; C_0603_1608Metric
C34: 10u; C_1206_3216Metric
C39: 4.7n; C_0603_1608Metric
C40, C41: 4.7p; C_0603_1608Metric
IC2: ATA6561-GAQW-N; SOIC127P600X175-8N; Manufacturer_Part_Number ATA6561-GAQW-N; Mouser Part Number 579-ATA6561-GAQW-N
Q2: BSS138; SOT-23; Manufacturer_Part_Number BSS138
R21, R22: 59; R_0603_1608Metric
R23: 560R; R_0603_1608Metric
R24: 100k; R_0603_1608Metric
U701, U702: GAQY212GS; SOP-4_3.8x4.1mm_P2.54mm; Manufacturer_Part_Number GAQY212GS

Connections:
+3.3V: C32.1, C33.1, IC2.5 (VIO); also elsewhere on the board
+5V: C34.1, C35.1, IC2.3 (VCC), R23.1; also elsewhere on the board
/CAN_BUS/CAN_H: C41.1, IC2.7 (CANH), R22.1; also elsewhere on the board
/CAN_BUS/CAN_L: C40.1, IC2.6 (CANL), R21.1; also elsewhere on the board
/CAN_BUS/CAN_RX: IC2.4 (RXD); also elsewhere on the board
/CAN_BUS/CAN_R_CTRL: Q2.1 (G), R24.1; also elsewhere on the board
/CAN_BUS/CAN_STBY: IC2.8 (STBY); also elsewhere on the board
/CAN_BUS/CAN_TX: IC2.1 (TXD); also elsewhere on the board
GND: C32.2, C33.2, C34.2, C35.2, C39.2, C40.2, C41.2, IC2.2 (GND), Q2.2 (S), R24.2; also elsewhere on the board
unnamed: C39.1, U701.3, U702.4
unnamed: Q2.3 (D), U702.2
unnamed: R21.2, U701.4
unnamed: R22.2, U702.3
unnamed: R23.2, U701.1
unnamed: U701.2, U702.1

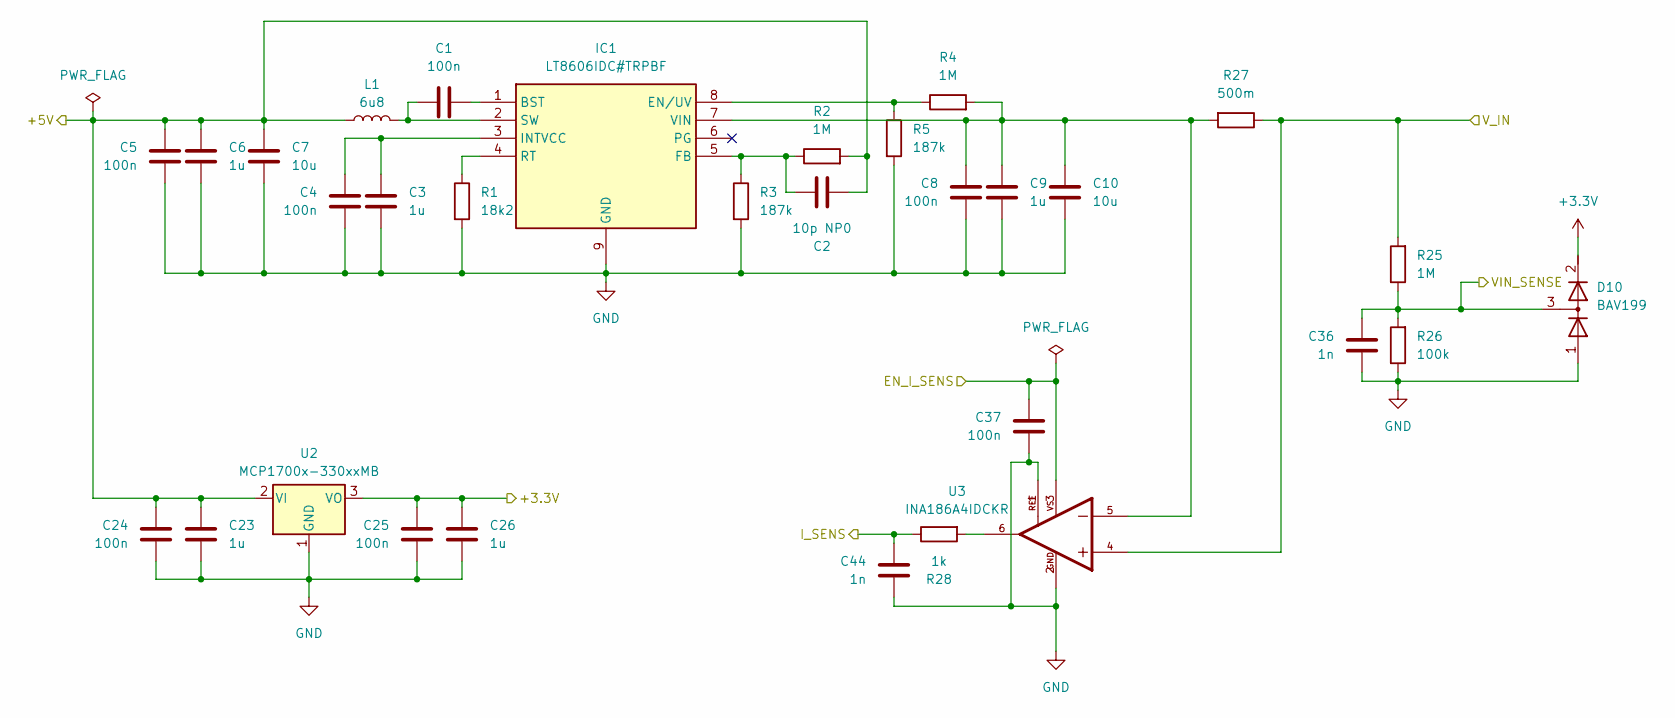
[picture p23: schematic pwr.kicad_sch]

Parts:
C1, C4, C5, C8, C24, C25, C37: 100n; C_0603_1608Metric
C2: 10p NP0; C_0603_1608Metric; Manufacturer_Part_Number 0603N100J500CT
C3, C6, C9, C23, C26: 1u; C_0603_1608Metric
C7, C10: 10u; C_1206_3216Metric
C36, C44: 1n; C_0603_1608Metric
D10: BAV199; TSOT-23; Manufacturer_Part_Number BAV199
IC1: LT8606IDC#TRPBF; SON45P200X200X80-9N-D; Manufacturer_Part_Number LT8606IDC#TRPBF; Mouser Part Number 584-LT8606IDCTRPBF
L1: 6u8; L_1210_3225Metric; Manufacturer_Part_Number LQH32PN6R8NN0L
R1: 18k2; R_0603_1608Metric
R2, R4, R25: 1M; R_0603_1608Metric
R3, R5: 187k; R_0603_1608Metric
R26: 100k; R_0603_1608Metric
R27: 500m; R_0603_1608Metric; Manufacturer_Part_Number CS0603-0R50-1%-HP
R28: 1k; R_0603_1608Metric
U2: MCP1700x-330xxMB; SOT-89-3; Manufacturer_Part_Number MCP1700T-3302E/MB
U3: INA186A4IDCKR; SOT65P210X110-6N; PARTREV B

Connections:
+3.3V: C25.2, C26.1, D10.2 (K), U2.3 (VO); also elsewhere on the board
+5V: C2.1, C5.2, C6.1, C7.1, C23.1, C24.2, L1.1, R2.2, U2.2 (VI); also elsewhere on the board
/MCU/EN_I_SENS: C37.2, U3.3; also elsewhere on the board
/MCU/I_SENS: C44.2, R28.1; also elsewhere on the board
/MCU/VIN_SENSE: C36.2, D10.3 (common), R25.1, R26.2; also elsewhere on the board
/PROTECTION/V_zas: R25.2, R27.1, U3.4; also elsewhere on the board
GND: C3.2, C4.1, C5.1, C6.2, C7.2, C8.1, C9.2, C10.2, C23.2, C24.1, C25.1, C26.2, C36.1, C37.1, C44.1, D10.1 (A), IC1.9 (GND), R1.2, R3.2, R5.2, R26.1, U2.1 (GND), U3.1, U3.2; also elsewhere on the board
unnamed: C1.2, IC1.1 (BST)
unnamed: IC1.8 (EN/UV), R4.1, R5.1
unnamed: C2.2, IC1.5 (FB), R2.1, R3.1
unnamed: C3.1, C4.2, IC1.3 (INTVCC)
unnamed: IC1.4 (RT), R1.1
unnamed: C1.1, IC1.2 (SW), L1.2
unnamed: C8.2, C9.1, C10.1, IC1.7 (VIN), R4.2, R27.2, U3.5
unnamed: R28.2, U3.6

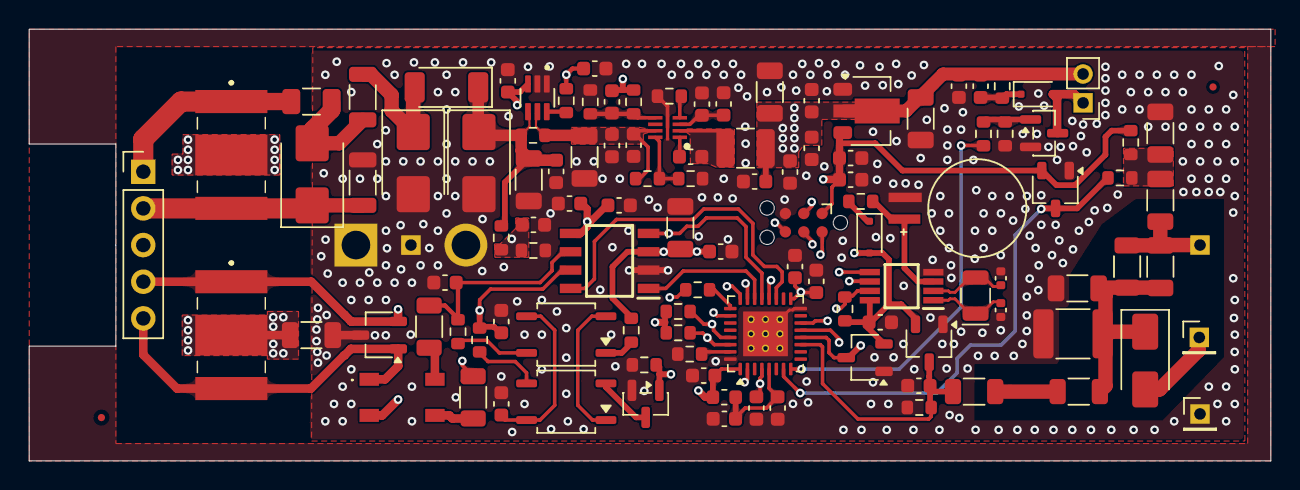
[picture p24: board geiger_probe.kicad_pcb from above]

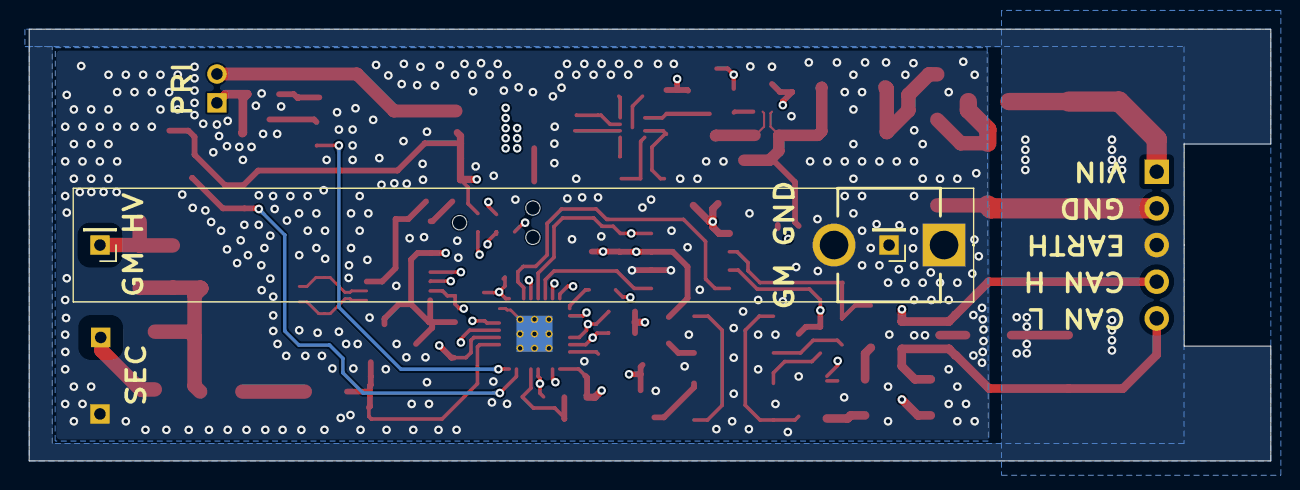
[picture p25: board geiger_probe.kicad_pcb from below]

Board: 4 copper layers, 86.0 x 29.9 mm, 116 parts (3 on the bottom side), 61 nets.

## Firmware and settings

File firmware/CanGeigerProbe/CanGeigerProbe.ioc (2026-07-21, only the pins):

Mcu.UserName=STM32L432KCUx
PA1.GPIO_Label=COMP_GM_IN
PA1.Signal=COMP1_INP
PA10.GPIO_Label=CAN_R_CTRL
PA10.Signal=GPIO_Output
PA11.Signal=CAN1_RX
PA12.Signal=CAN1_TX
PA2.GPIO_Label=FBACK_CTRL
PA2.Signal=S_TIM2_CH3
PA5.GPIO_Label=HV_meas
PA5.Signal=ADCx_IN10
PA6.GPIO_Label=VIN_SENSE
PA6.Signal=ADCx_IN11
PA7.GPIO_Label=I_SENS
PA7.Signal=ADCx_IN12
PA9.GPIO_Label=CAN_STBY
PA9.Signal=GPIO_Output
PB0.GPIO_Label=EN_I_SENS
PB0.Signal=GPIO_Output
PB6.Signal=I2C1_SCL
PB7.Signal=I2C1_SDA

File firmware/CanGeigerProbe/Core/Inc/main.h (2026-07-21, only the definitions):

#define COMP_GM_IN_Pin GPIO_PIN_1
#define COMP_GM_IN_GPIO_Port GPIOA
#define FBACK_CTRL_Pin GPIO_PIN_2
#define FBACK_CTRL_GPIO_Port GPIOA
#define HV_meas_Pin GPIO_PIN_5
#define HV_meas_GPIO_Port GPIOA
#define VIN_SENSE_Pin GPIO_PIN_6
#define VIN_SENSE_GPIO_Port GPIOA
#define I_SENS_Pin GPIO_PIN_7
#define I_SENS_GPIO_Port GPIOA
#define EN_I_SENS_Pin GPIO_PIN_0
#define EN_I_SENS_GPIO_Port GPIOB
#define CAN_STBY_Pin GPIO_PIN_9
#define CAN_STBY_GPIO_Port GPIOA
#define CAN_R_CTRL_Pin GPIO_PIN_10
#define CAN_R_CTRL_GPIO_Port GPIOA
#define SWDIO_Pin GPIO_PIN_13
#define SWDIO_GPIO_Port GPIOA
#define SWCLK_Pin GPIO_PIN_14
#define SWCLK_GPIO_Port GPIOA
#define CAN_RX_IT_Pin GPIO_PIN_15
#define CAN_RX_IT_GPIO_Port GPIOA
#define SWO_Pin GPIO_PIN_3
#define SWO_GPIO_Port GPIOB

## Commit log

2026-07-20 Initial schematic
    [can_bus.kicad_sch, geiger_probe.kicad_pcb, geiger_probe.kicad_sch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]
2026-07-20 Sch almost done, maybe add current sense
    [can_bus.kicad_sch, geiger_probe.kicad_sch, hv.kicad_sch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]
2026-07-21 Scheamtic almost finished, astarted firmware and pcb
    [INA186A4IDCKR.step, can_bus.kicad_sch, geiger_probe.kicad_pcb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]
2026-07-21 Schematic finished, first routing
    [CDM1209-05A-MP-F12-67.step, can_bus.kicad_sch, geiger_probe.kicad_pcb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]
2026-07-22 Routing almost finished
    [can_bus.kicad_sch, geiger_probe.kicad_pcb, hv.kicad_sch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]
2026-07-22 Finished routing, needs polishing
    [geiger_probe.kicad_pcb]
2026-07-23 PDF files for the geiger_probe schematic and PCB were added, and output file paths in the configuration were updated.
    [can_bus.kicad_sch]
2026-08-07 README: aktualizacja do stanu v5.0 + rendery 3D
    - opis zsynchronizowany ze schematem/layoutem: MCP1700 zamiast TPS7A0230,
    INA186 (current sense), RTC MCP79410, terminacja CAN na PhotoMOS, GDT 3R090-5S
    - dodana sekcja "Plytka" z renderami z media/ (angle, top, bottom)
    - tabela arkuszy hierarchicznych i linki do plikow produkcyjnych w prod/
    - sekcja Firmware (szkielet CubeMX), poprawiony refdes rezystora gaszacego R12
    - usuniety martwy link do nieistniejacego docs/
    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
2026-08-21 DRC fix
    [geiger_probe.kicad_pcb]
2026-08-27 Unify resistor/capacitor values and footprints, add via-in-pad DRC rule, regenerate outputs
    [can_bus.kicad_sch, geiger_probe.kicad_pcb, hv.kicad_sch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]
2026-09-25 Add J1 net labels and fiducials, regenerate production outputs
    - Named nets on J1 pads (schematic + PCB)
    - 2 fiducials for stencil alignment (hand assembly)
    - Regenerate PDFs, gerber zip, interactive BOM and 3D renders
    [geiger_probe.kicad_pcb, geiger_probe.kicad_sch, hv.kicad_sch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]
2026-09-28 Fix BOM data: correct MPNs for C16/C19, HV resistor part numbers for R9/R10/R12
    [hv.kicad_sch, prot.kicad_sch, pwr.kicad_sch]
2026-09-28 Regenerate production outputs and gerber zip after BOM field fixes
2026-11-08 lib_local: SMT nut M2 footprint (Sinhoo SMTSO2005CTJ / SMTSO2010CTJ, PEM SMTSO compatible, plated ring both sides) + 3D models H0.5 / H1.0
2026-11-08 M12 connector: SMT M2 nuts H1/H2 (Sinhoo SMTSO, lib_local footprint) on Earth; zones refilled; regenerate gerbers (zip), PDFs and renders
2026-11-08 BOM fields: MPN / Manufacturer / LCSC / TME / Mouser from Big_order_2026 rev.2 order (unified part numbers), old sourcing fields (Manufacturer_Part_Number, MF, MP, Mouser/Arrow/TME price fields, Snap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
2026-11-08 PCB updated from schematic (F8: MPN/LCSC/TME/Mouser fields); regenerate gerber zip, iBOM (MPN/LCSC/TME/Mouser columns), BOM and PDFs; zones refilled

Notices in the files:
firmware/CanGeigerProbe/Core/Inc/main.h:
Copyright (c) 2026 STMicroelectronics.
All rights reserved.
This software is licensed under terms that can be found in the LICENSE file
